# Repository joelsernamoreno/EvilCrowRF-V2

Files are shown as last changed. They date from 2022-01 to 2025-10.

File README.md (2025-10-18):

# EvilCrowRF-V2

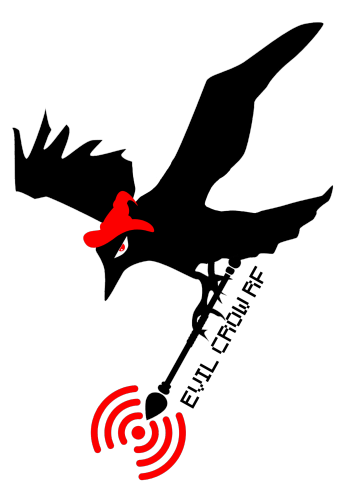
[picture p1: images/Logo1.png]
EvilCrow


**Idea, development and implementation:** Joel Serna (@JoelSernaMoreno).

**Main collaborator:** Little Satan (https://github.com/LSatan/)

**Other collaborators:** Jordi Castelló (@iordic), Eduardo Blázquez (@_eblazquez), Federico Maggi (@phretor), Andrea Guglielmini (@Guglio95) and RFQuack (@rfquack).

**PCB design:** Ignacio Díaz Álvarez (@Nacon_96), Forensic Security (@ForensicSec) and April Brother (@aprbrother).

**Manufacturer and distributor:** April Brother (@aprbrother).

**Distributor from United Kingdom:** KSEC Worldwide (@KSEC_KC).

The developers and collaborators of this project do not earn money with this. 
You can invite me for a coffee to further develop Low-Cost hacking devices. If you don't invite me for a coffee, nothing happens, I will continue developing devices.



**Available with April Brother (shipping from China):** 

* Evil Crow RF V2 Tindie: https://www.tindie.com/products/aprbrother/evil-crow-rf-v2-rf-transceiver-rf/
* Evil Crow RF V2 Alibaba: https://www.alibaba.com/product-detail/Evil-Crow-RF2-signal-receiver-with_1600467911757.html 
* Evil Crow RF V2 Aliexpress: https://www.aliexpress.com/item/3256807682636637.html

**Available with SAPSAN Cybersec & Military (shipping from EU, Poland):**

* https://sapsan-sklep.pl/en/products/evil-crow-rf-v2

**Available with KSEC Worldwide (shipping from United Kingdom):**

* Evil Crow RF V2: https://labs.ksec.co.uk/product/evil-crow-rf-v2/
* Evil Crow RF V2 Lite: https://labs.ksec.co.uk/product/evil-crow-rf2-lite/

**Available with Tienda Espía (shipping from Mexico):**

* https://tiendaespia.com.mx/producto/evil-crow-rf-v2-radiofrequency-hacking-device/

**Discord Group:** https://discord.gg/evilcrowrf

**Summary:**

1. Disclaimer
2. Introduction
3. Firmware
	* Installation
	* First steps with Evil Crow RF V2
	* Home
	* RX Config
	* Log Viewer
	* TX Config
	* Config
4. Evil Crow RF V2 Support
5. Other compatible firmware

# Disclaimer

Evil Crow RF V2 is a basic device for professionals and cybersecurity enthusiasts.

We are not responsible for the incorrect use of Evil Crow RF V2.

We recommend using this device for testing, learning and fun :D

**Be careful with this device and the transmission of signals. Make sure to follow the laws that apply to your country.**

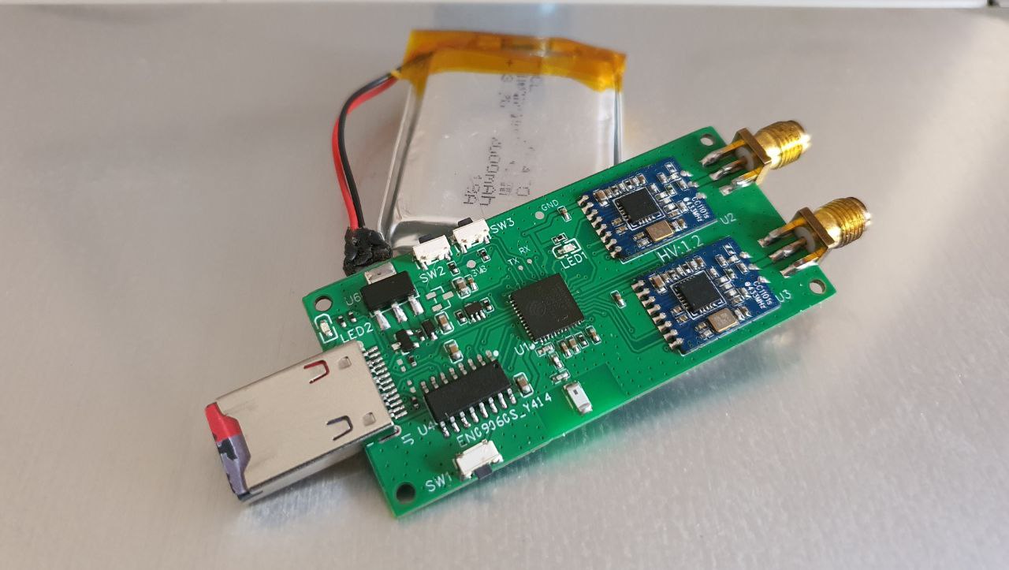
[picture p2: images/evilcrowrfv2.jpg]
EvilCrowRF


# Introduction

Evil Crow RF V2 is a radiofrequency hacking device for pentest and Red Team operations, this device operates in the following radiofrequency bands:

* 300Mhz-348Mhz
* 387Mhz-464Mhz
* 779Mhz-928Mhz
* 2.4GHz

Evil Crow RF V2 has two CC1101 radiofrequency modules, these modules can be configured to transmit or receive on different frequencies at the same time. Additionally, Evil Crow RF V2 has a NRF24L01 module for other attacks.

Evil Crow RF V2 allows the following attacks:

* Signal receiver
* Signal transmitter
* Replay attack
* Mousejacking
* ...

**NOTE:** 

* All devices have been flashed with basic firmware Evil Crow RF V2 before shipping.
* Please do not ask me to implement new functions in this code. You can develop code for Evil Crow RF V2 and send PR with your new code.

# Firmware

The basic firmware allows to receive and transmit signals. You can configure the two radio modules through a web panel via WiFi.

## Installation

1. Install esptool: sudo apt install esptool
2. Install pyserial: sudo pip install pyserial
3. Download and install the latest version of Arduino IDE (v2.3.6): https://www.arduino.cc/en/main/software
4. Download Evil Crow RF V2 repository: git clone https://github.com/joelsernamoreno/EvilCrowRF-V2.git
5. Download the ESPAsyncWebServer library in the Arduino library directory: git clone https://github.com/ESP32Async/ESPAsyncWebServer.git
6. Download the ElegantOTA library in the Arduino library directory: git clone https://github.com/ayushsharma82/ElegantOTA.git
7. Edit ElegantOTA/src/ElegantOTA.h and chage the following:

* #define ELEGANTOTA_USE_ASYNC_WEBSERVER 0 to #define ELEGANTOTA_USE_ASYNC_WEBSERVER 1

8. Download the AsyncTCP library in the Arduino library directory: git clone https://github.com/ESP32Async/AsyncTCP.git
9. Open Arduino IDE
10. Go to File - Preferences. Locate the field "Additional Board Manager URLs:" Add "https://espressif.github.io/arduino-esp32/package_esp32_index.json" without quotes. Click "Ok"
11. Select Tools - Board - Boards Manager. Search for "esp32". Install "esp32 by Espressif system version 3.3.2". Click "Close".
12. Open the EvilCrowRF-V2/firmware/firmware/firmware.ino sketch
13. Select Tools:
    * Board - "ESP32 Dev Module".
    * Flash Size - "4MB (32Mb)".
    * CPU Frequency - "80MHz (WiFi/BT)".
    * Flash Frequency - "40MHz"
    * Flash Mode - "DIO"
14. Upload the code to the Evil Crow RF V2 device
15. Copy the EvilCrowRF-V2/firmware/SD/HTML folder to a MicroSD card.

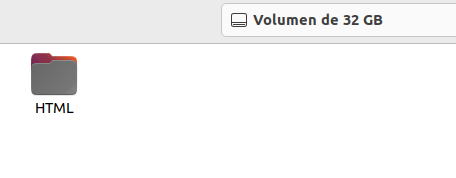
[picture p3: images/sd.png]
SD


**Notes about SD:** 

* Web server will not load, is a blank page or displays nothing:

Check you have copied the relevant files to the SD card and the SD card is inserted in the Evil Crow RF V2 device.

* My files are on the SD card but the web server will not work:

Check your SD card size. It is recommended to use a small card. 32GB or smaller is sufficent for operation. Cards larger than this have been shown to cause issues and not work.

## First steps with Evil Crow RF V2

0. Check & verify you have copied the relevant files to your SD card.
1. Insert the MicroSD card into the Evil Crow RF V2 and connect the device to an external battery or laptop.
2. Set up a Wi-Fi AP with your mobile phone:
	* **SSID:** Evil Crow RF v2
	* **Password:** 123456789ECRFv2
3. Connect your laptop to the same Wi-Fi network.
4. Open a browser and access the web panel: http://evilcrow-rf.local/

**Note:** If you cannot access the web panel, use the IP address assigned to Evil Crow RF v2 or follow below steps **only if you are running Linux OS:**
 * check if avahi-deamon is installed and running on your PC. You can do this with executing "sudo systemctl status avahi-daemon" in terminal
 * If service is not running, install it using your package manager (apt, yum, dnf, Packman, rpm,...)
 * After successful installation, start avahi-daemon service with "sudo systemctl start avahi-daemon && sudo systemctl enable avahi-daemon"
 * In case evilcrow-rf.local is still not reachable, use http://"IP address", where "IP address" is IP assigned to Evil Crow RF v2.

## Home

The Home page shows interesting information about the device.

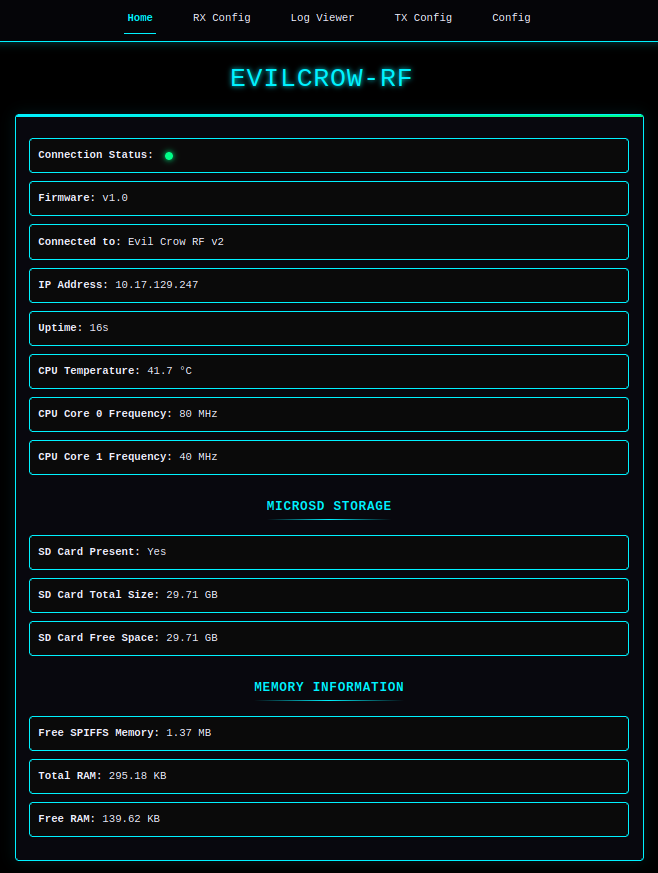
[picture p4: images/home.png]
Home


## RX Config

The RX Config page allows you to configure the CC101 modules for receiving signals. The received signals are displayed in the Log Viewer.

* Module: (1 for first CC1101 module, 2 for second CC1101 module)
* Modulation: (example ASK/OOK)
* Frequency: (example 433.92)
* Rx bandwidth: (example 200)
* Deviation: (example 0)
* Data rate: (example 5)

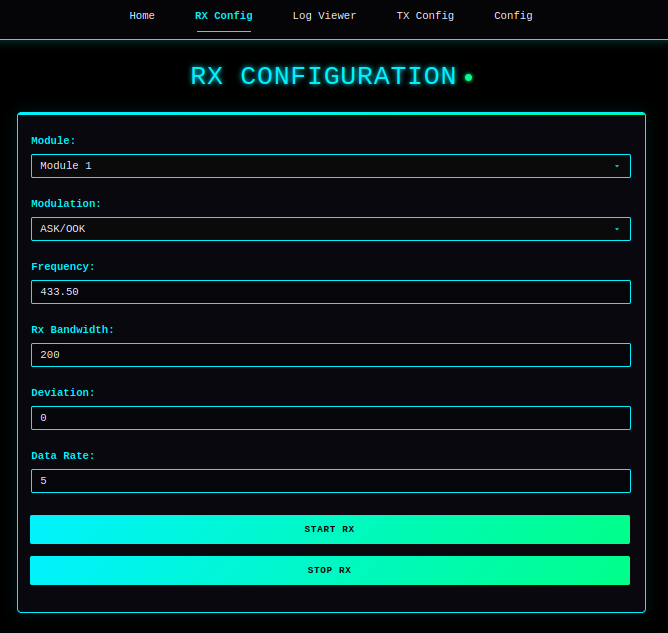
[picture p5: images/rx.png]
RX


## Log Viewer

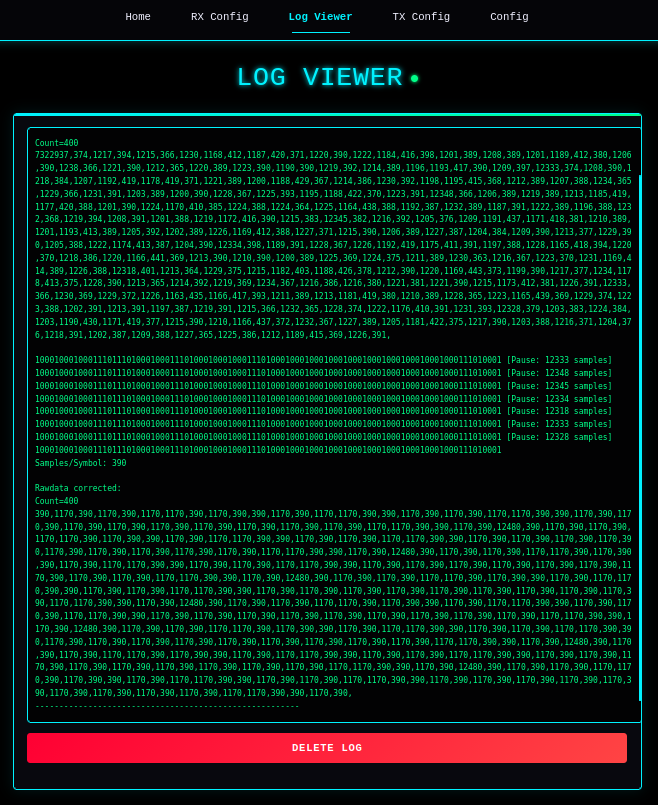
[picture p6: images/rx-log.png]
RXLog


## TX Config

The TX Config page allows you to transmit a raw data signal or enable/disable the jammer.

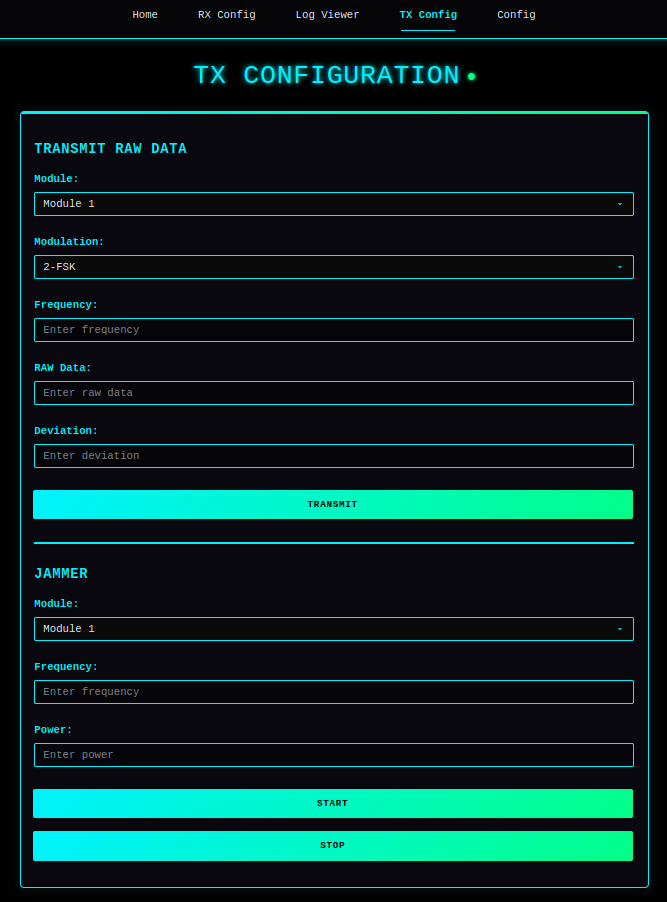
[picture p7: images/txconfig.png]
TXCONFIG


* **TX Raw Data:**

* Module: (1 for first CC1101 module, 2 for second CC1101 module)
* Modulation: (example ASK/OOK)
* Frequency: (example 433.92)
* RAW Data: (raw data or raw data corrected displayed in Log Viewer)
* Deviation: (example 0)

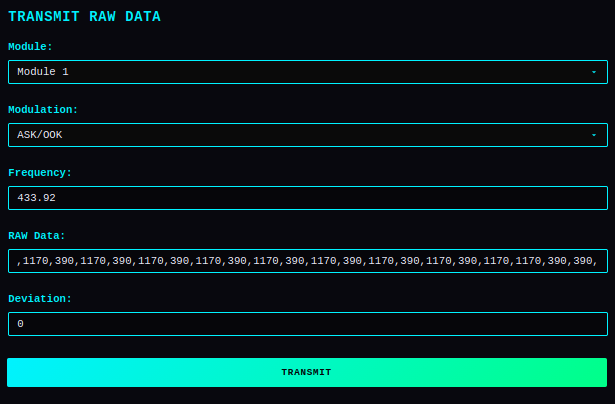
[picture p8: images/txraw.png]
TXRAW


* **Jammer:**

* Module: (1 for first CC1101 module, 2 for second CC1101 module)
* Frequency: (example: 433.92)
* Jammer Power: (example: 12)

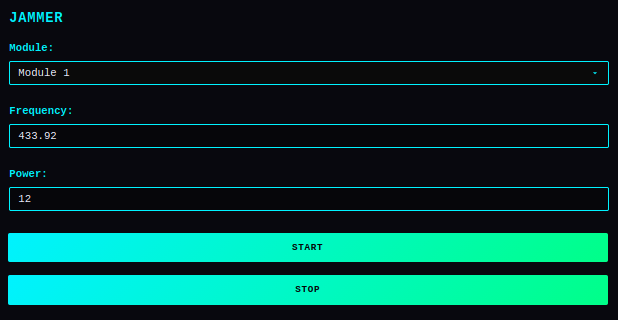
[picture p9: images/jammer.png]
JAMMER


## Config

The Config page allows you to change the Wi-Fi configuration.

**NOTE:** Evil Crow RF V2 is configured in STATION MODE. You can change the ssid and password from the web panel.

The changes will be stored in the device, every time you restart Evil Crow RF V2 the new Wi-Fi settings will be applied. If you want to return to the default settings, you can delete the stored Wi-Fi configuration from the web panel.

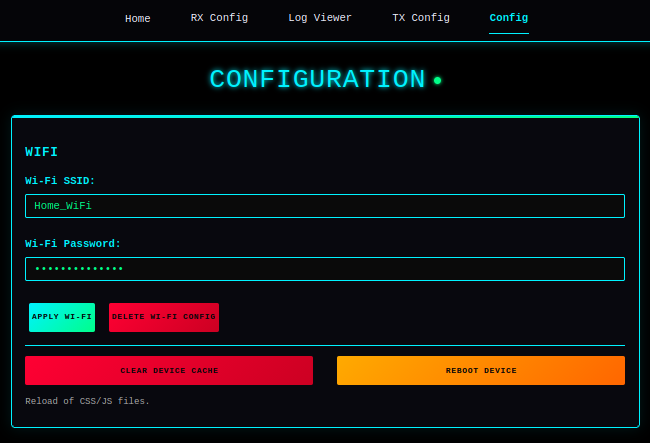
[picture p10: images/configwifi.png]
CONFIG


# Evil Crow RF V2 Support

* You can ask in the Discord group: https://discord.gg/jECPUtdrnW
* You can open issue or send me a message via twitter (@JoelSernaMoreno).

# Other compatible firmware

**You can also use alternative firmware options, for example:**

* https://github.com/h-RAT/EvilCrowRF_Custom_Firmware_CC1101_FlipperZero

* https://github.com/realdaveblanch/Evil-Crow-RF-v2-Custom-ROM/

* https://github.com/tutejshy-bit/tut-rf

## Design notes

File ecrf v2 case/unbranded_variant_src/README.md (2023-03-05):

### Enclosure Remix

- Smaller USB cap (https://www.thingiverse.com/thing:2816192)
- Recomissioned new design using Solidworks (files included)
- Longer button
- Removed "evil" naming
- Removed signal symbol (splash protection)

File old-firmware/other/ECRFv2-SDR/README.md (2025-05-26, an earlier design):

# EvilCrow RF v2 - Enhanced SDR Implementation

**🔗 Based on the original [EvilCrow RF v2](https://github.com/joelsernamoreno/EvilCrowRF-V2) by Joel Serna Moreno**

This enhanced firmware transforms your EvilCrow RF v2 into a powerful Software Defined Radio (SDR) compatible with Universal Radio Hacker (URH) and other professional RF analysis tools.

## 🙏 Attribution & Credits

This project builds upon the excellent work of:

- **Joel Serna Moreno** - Original EvilCrow RF v2 creator
- **Original Repository**: https://github.com/joelsernamoreno/EvilCrowRF-V2
- **Hardware Design**: EvilCrow RF v2 by Joel Serna Moreno

## 🔄 Contributing Back

Improvements and features developed here are intended to be contributed back to the original EvilCrow project via pull requests to help the entire community.

## 🔓 Wireless security testing on a budget.

**Would you rather pay cose to 500$ for the HackRF, instead of paying just 35~$ for the Evil Crow v2?**

This firmware transforms you Evil Crow Device in to a multifunctional, sub-Ghz, wireless security auditing tool.
If you have no need for >1GHz band access you stand to save a few hundred dollars while getting extremely high value for your money if you choose Evil Crow v2 + SDR firmware over, say, the Hack RF One which will cost you about 10x more.

## ✅ **Enhanced Features**

- **Proper CC1101 library integration** - Uses ELECHOUSE_CC1101_SRC_DRV.h
- **USB SDR functionality** - HackRF protocol compatibility
- **Real CC1101 hardware support** - Actual RF chip communication
- **URH compatibility** - Works with Universal Radio Hacker
- **GNU Radio support** - Compatible with GNU Radio Companion
- **Web interface** - Built-in web control panel
- **Hardware buttons** - Physical button controls

## 🔧 **Hardware Requirements**

- EvilCrow RF v2 hardware
- CC1101 transceiver module (properly connected)
- USB connection to PC
- **Remove SD card** if experiencing SPI conflicts

## 📋 **Installation**

1. **Open Arduino IDE**
2. **Load firmware**: `EvilCrow-SDR-Working.ino`
3. **Select board**: ESP32 Dev Module
4. **Verify all files are present**:
   - `EvilCrow-SDR-Working.ino` (main firmware)
   - `ELECHOUSE_CC1101_SRC_DRV.h` (library header)
   - `ELECHOUSE_CC1101_SRC_DRV.cpp` (library implementation)
5. **Upload** to EvilCrow

**Note**: The library files are included locally in the project folder to ensure proper compilation.

## 🚀 **Usage**

### **USB SDR Mode**

1. **Connect EvilCrow** to PC via USB
2. **Open serial terminal** (115200 baud)
3. **Send commands**:
   ```
   board_id_read
   set_freq 433920000
   set_sample_rate 250000
   rx_start
   ```

### **URH Integration**

1. **Start this firmware** on EvilCrow
2. **Run URH bridge**:
   ```bash
   python3 urh_compatible_bridge.py
   ```
3. **In URH**: Select RTL-TCP, IP: 127.0.0.1, Port: 1234
4. **Click Start** in URH

### **Web Interface**

1. **Connect to WiFi**: "EvilCrow-SDR" (password: "123456789")
2. **Open browser**: http://192.168.4.1
3. **Control SDR** via web interface

## 📡 **Supported Commands**

| Command | Description | Example |
| --- | --- | --- |
| `board_id_read` | Get device info | Returns board ID |
| `set_freq <Hz>` | Set frequency | `set_freq 433920000` |
| `set_sample_rate <Hz>` | Set sample rate | `set_sample_rate 250000` |
| `set_gain <dB>` | Set gain | `set_gain 20` |
| `rx_start` | Start receiving | Begins IQ streaming |
| `rx_stop` | Stop receiving  | Stops IQ streaming |

## 🔘 **Hardware Buttons**

- **Button 1**: Toggle RX mode on/off
- **Button 2**: Cycle through frequencies (315, 433.92, 868, 915 MHz)

## 🌐 **Web API Endpoints**

| Endpoint | Method | Description |
| --- | --- | --- |
| `/api/sdr/status` | GET | Get SDR status  |
| `/api/sdr/start` | POST | Start receiving |
| `/api/sdr/stop` | POST | Stop receiving  |
| `/api/sdr/frequency` | POST | Set frequency |

## 🔍 **Troubleshooting**

### **CC1101 Not Detected**

1. **Remove SD card** (SPI conflict)
2. **Check connections** (power, SPI pins)
3. **Verify 3.3V power** to CC1101
4. **Try different firmware** if needed

### **URH Connection Issues**

1. **Ensure bridge is running** on port 1234
2. **Check serial port** (/dev/cu.usbserial-140)
3. **Verify CC1101 initialization** in serial output
4. **Use correct URH settings** (RTL-TCP, 127.0.0.1:1234)

### **No RF Data**

1. **Check antenna connection**
2. **Verify frequency settings**
3. **Ensure RX mode is active**
4. **Check for RF signals** in environment

## 📊 **Expected Output**

### **Successful Startup**

```
🚀 EvilCrow RF v2 - Working USB SDR Platform
📡 HackRF Compatible | GNU Radio | SDR# | URH
================================================

📻 Initializing SDR subsystem...
✅ SDR subsystem initialized
🔌 Setting up pins... ✅ Success
📡 Initializing CC1101 with ELECHOUSE library... ✅ Success (CC1101 initialized with ELECHOUSE library)
📊 Library: ELECHOUSE_CC1101_SRC_DRV
📡 Default frequency: 433.92 MHz
📻 Mode: RX
📶 Setting up WiFi Access Point... ✅ Success
🌐 IP Address: 192.168.4.1
🌐 Setting up web server... ✅ Success

🎉 EvilCrow SDR initialization complete!
📻 SDR Mode: Ready
🌐 Web Interface: http://192.168.4.1

✅ EvilCrow SDR is ready!
🔗 Connect via USB and send commands
```

## 🎯 **Why This Works**

1. **Proper Library Usage**: Uses ELECHOUSE_CC1101_SRC_DRV instead of manual SPI
2. **Correct Initialization**: Follows proper CC1101 init sequence
3. **Real Data**: Reads actual RF data from CC1101 FIFO
4. **Stable Communication**: Proper SPI handling and timing
5. **Hardware Compatibility**: Works with actual EvilCrow hardware

## **🚀 What This Architecture Enables:**

🖥️ Unlimited Processing Power
No more ESP32 memory limits (32KB → Gigabytes)
No more CPU constraints (240MHz → Multi-GHz multi-core)
Complex algorithms that were impossible on ESP32
Real-time analysis of multiple signals simultaneously

🎨 Advanced User Interfaces
Professional desktop applications (Python/Qt, Electron, etc.)
Web-based dashboards with real-time visualizations
Mobile apps that connect to EvilCrow
Integration with existing tools (URH, GNU Radio, etc.)

🧠 AI-Powered RF Analysis
Machine learning for automatic protocol detection
Neural networks for signal classification
Pattern recognition for unknown protocols
Automated attack generation

🎯 Specific New Possibilities:
1. Advanced Signal Analysis Engine
2. Professional Attack Framework
Automated vulnerability scanning of RF devices
Protocol fuzzing with intelligent mutations
Real-time jamming with adaptive algorithms
Coordinated multi-frequency attacks
3. Database-Driven Operations
Massive signal fingerprint database (millions of devices)
Cloud-synchronized attack patterns
Historical analysis of captured signals
Collaborative threat intelligence
4. Advanced Visualization
3D spectrum analysis in real-time
Waterfall displays with infinite history
Protocol flow diagrams
Attack success probability heatmaps

🛠️ Implementation Ideas:
Option 1: Enhanced Python Framework
Option 2: Web-Based Command Center
Real-time dashboard showing all RF activity
Drag-and-drop attack builder
Live spectrum analyzer
Remote control from anywhere
Option 3: Integration Platform
GNU Radio integration for custom DSP
Wireshark plugins for RF protocols
Metasploit modules for RF exploitation
OSINT integration for target intelligence

🎯 Immediate Next Steps:
1. Enhanced Bridge Framework
A more powerful bridge that supports:
Multiple simultaneous connections
Plugin architecture for custom protocols
Real-time signal processing
Advanced attack modes
2. Professional Web Interface
Real-time spectrum display
Protocol decoder dashboard
Attack automation interface
Signal database management
3. AI-Powered Analysis
Automatic protocol detection
Vulnerability assessment
Attack recommendation engine
Success probability prediction

🏆 This Changes Everything!
This firmware essentially opens up for a "EvilCrow Pro" architecture where:

✅ EvilCrow = High-quality RF frontend

✅ Computer = Unlimited processing power

✅ Bridge = Seamless integration

✅ Result = Professional-grade RF security platform

This could compete with $10,000+ commercial RF security tools! 💰

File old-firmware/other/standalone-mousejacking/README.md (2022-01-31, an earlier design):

# EvilCrowRF-V2 Mousejacking

Sketch for using Evil Crow RF V2 as Mousejacking Mass Pwner Standalone Tool.
Once flashed into Evil Crow RF V2, it will automatically search and attack all vulnerable Mice & Keyboards around.

BE CAREFUL!

This is based on uCMousejack[1] and WHID Elite[2].
[1] https://github.com/phikshun/uC_mousejack
[2]https://github.com/whid-injector/whid-31337

P.S. This standalone mode doesn't need to be plugged into a PC to work. Is enough to plug the Evil Crow RF V2 on a USB-battery-pack or use a LiPo and enjoy a MouseDriving session. ;]

By default the payload executes cmd and writes a test text, setup to run into the Attack.h.
If you wanna create your own payload... go in the directory Payload_Generator_Mousejacking_Attack and:
1.- Edit ducky.txt and type your payload
2.- Run: ./attack_generator.py ducky.txt

This will create a new attack.h, you will have to use this in the mousejacking sketch

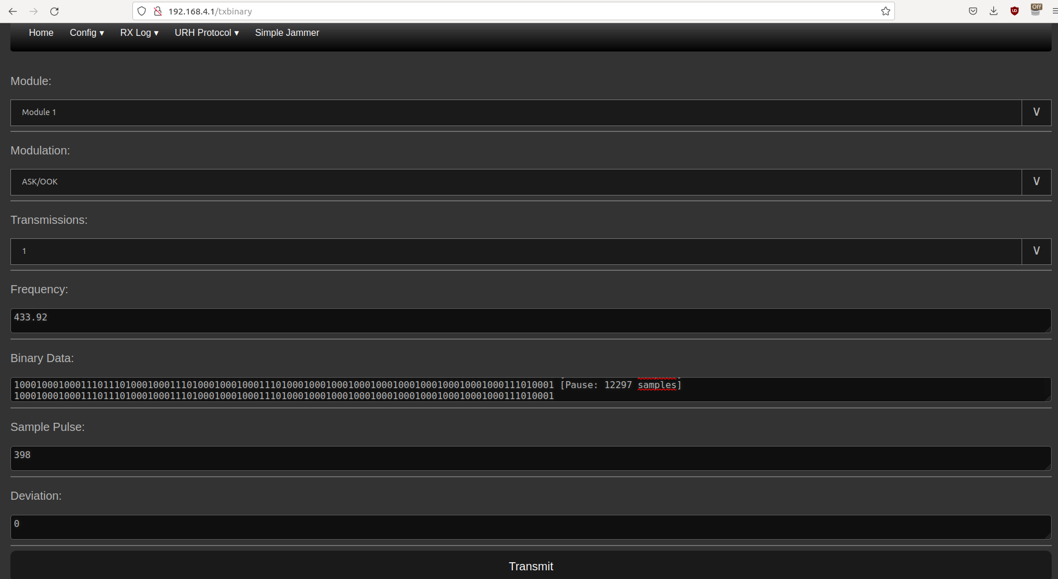
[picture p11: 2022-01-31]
images/txbinary.png

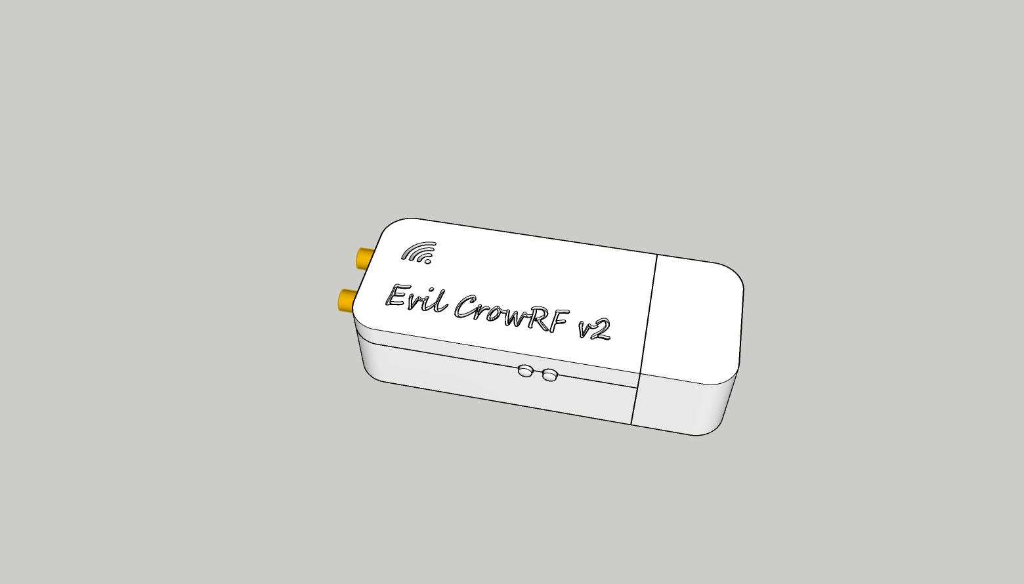
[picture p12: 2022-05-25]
ecrf v2 case/Variant 1/V2 Case akku pre v1.jpg

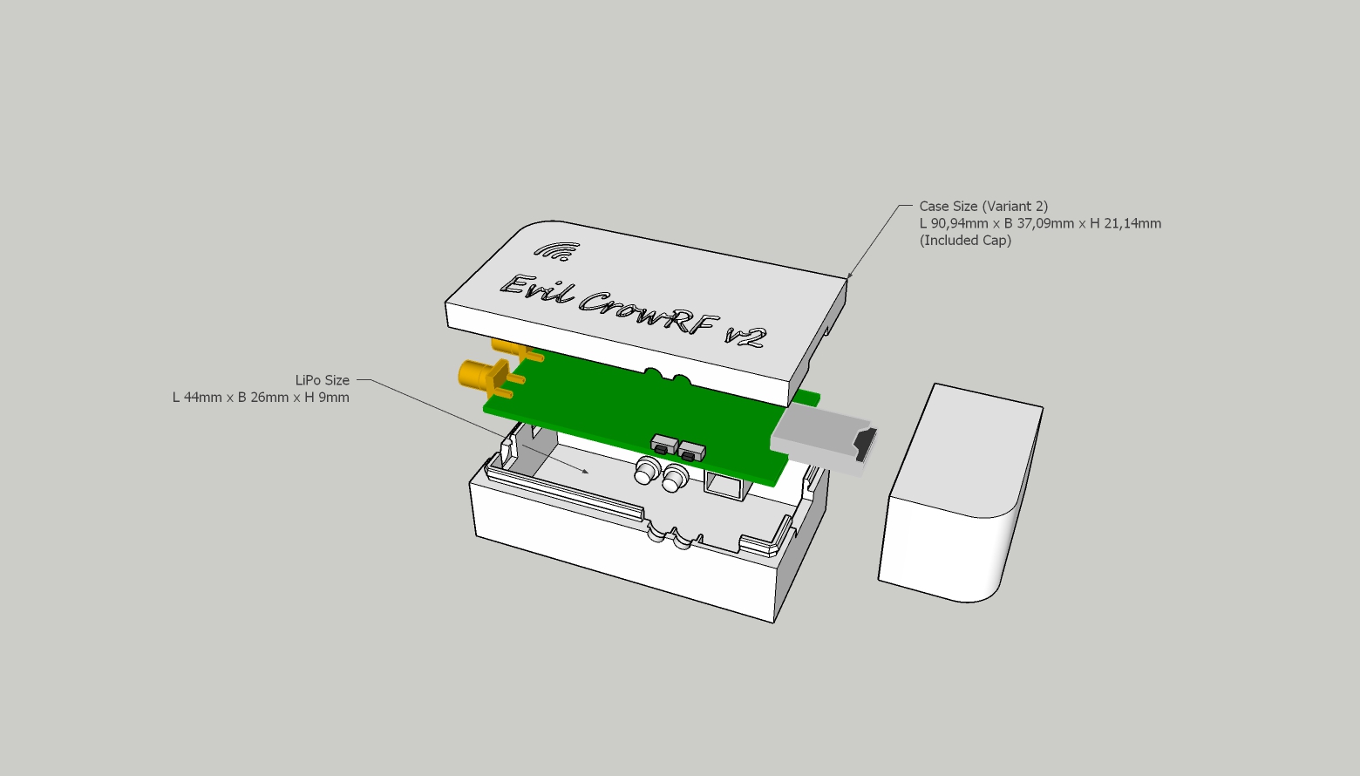
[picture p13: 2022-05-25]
ecrf v2 case/Variant 2/V2 Case akku exp v2.jpg

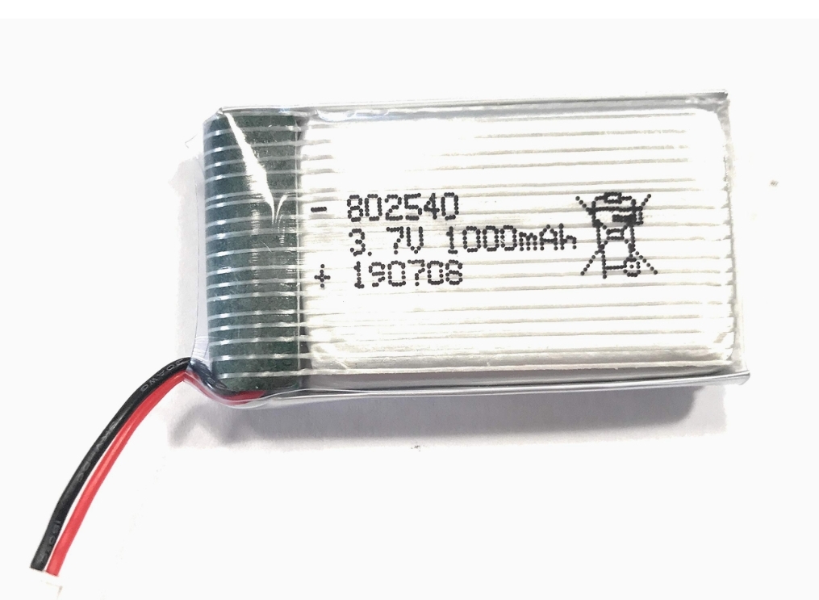
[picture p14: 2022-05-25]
ecrf v2 case/Lipo 1000mAh 44x26x9.jpg

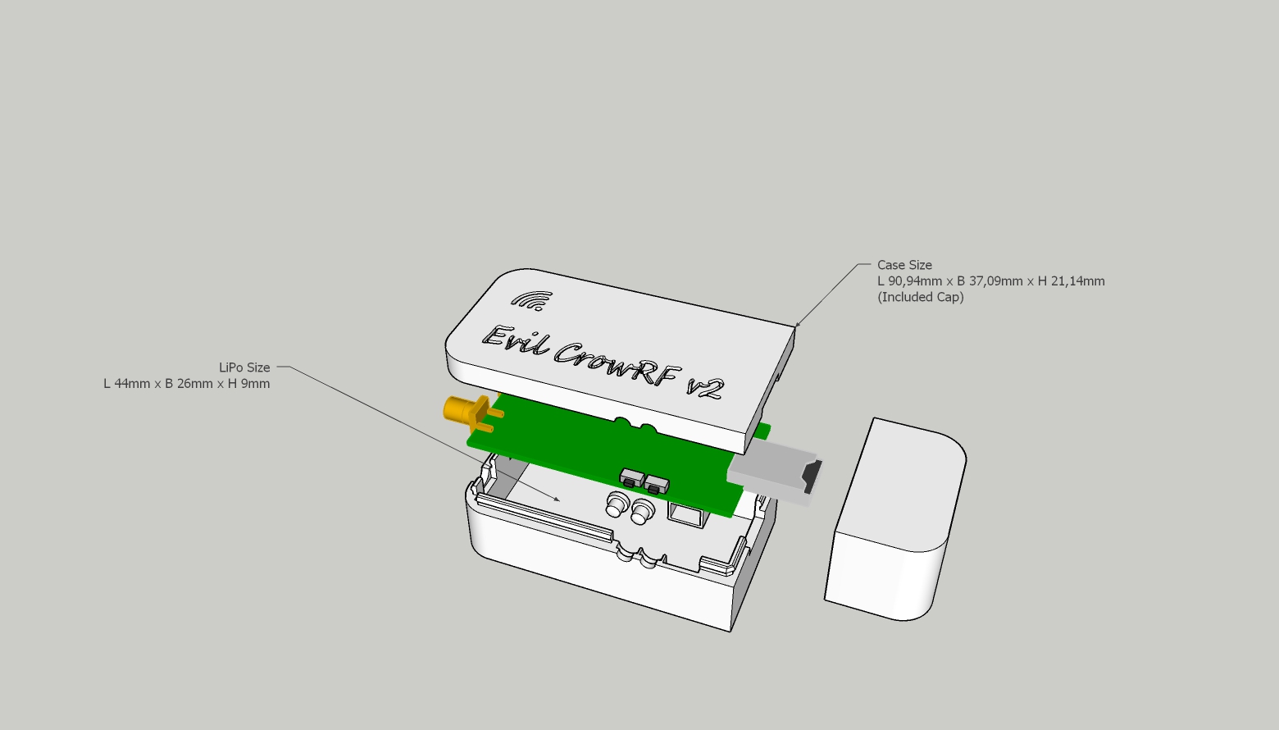
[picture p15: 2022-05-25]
ecrf v2 case/Variant 1/V2 Case akku exp v1.jpg

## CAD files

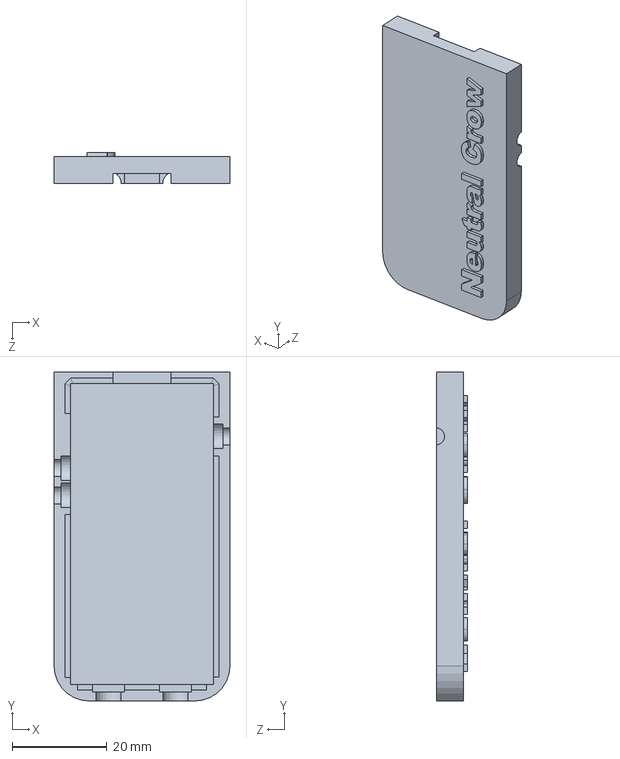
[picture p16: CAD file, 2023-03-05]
ecrf v2 case/unbranded_variant_src/solidworks/Top.SLDPRT
37.1 x 69.3 x 6.46 mm

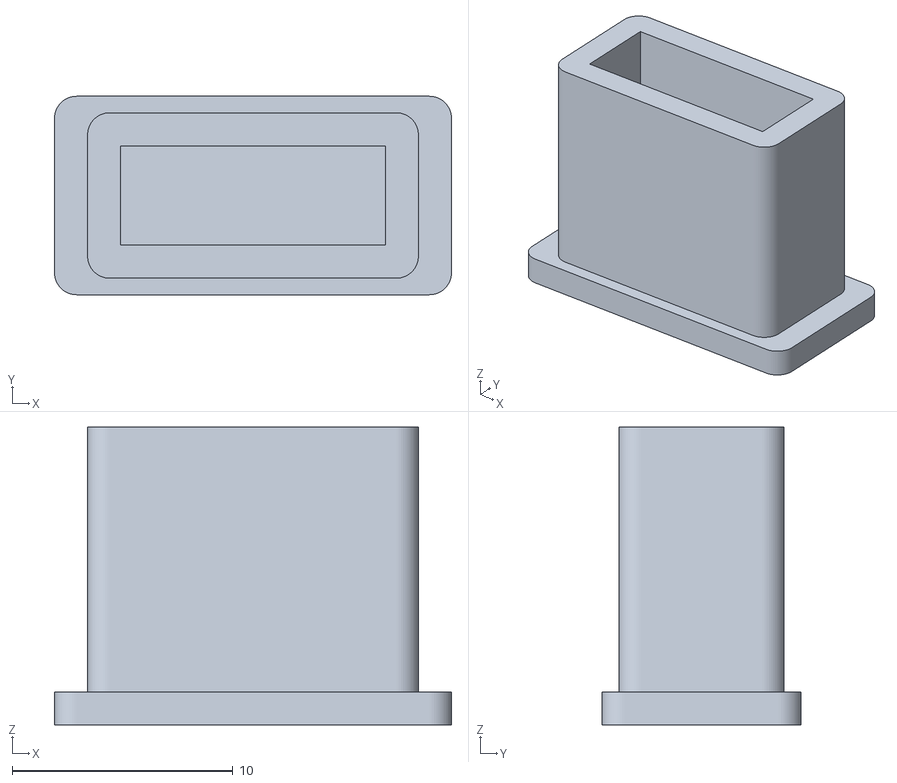
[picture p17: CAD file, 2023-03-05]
ecrf v2 case/unbranded_variant_src/stl/NCRFV1_USB_CAP.STL
18.0 x 9.00 x 13.5

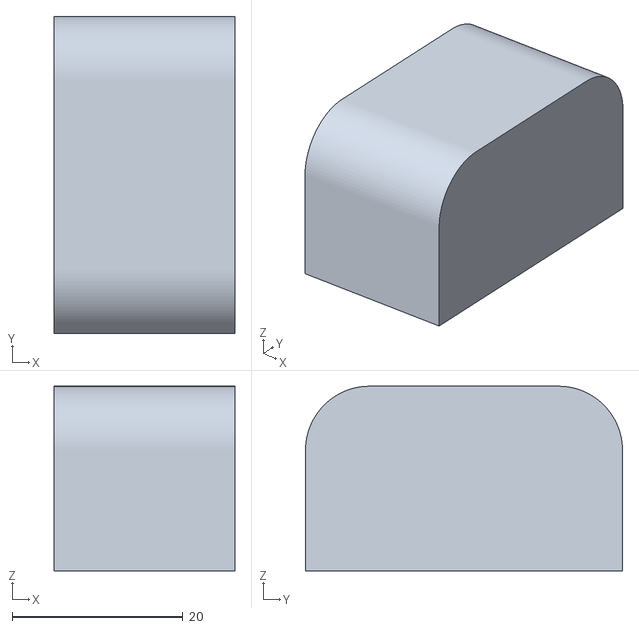
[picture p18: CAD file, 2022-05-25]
ecrf v2 case/Variant 1/ECRFV2_CAP.stl
21.1 x 37.1 x 21.6

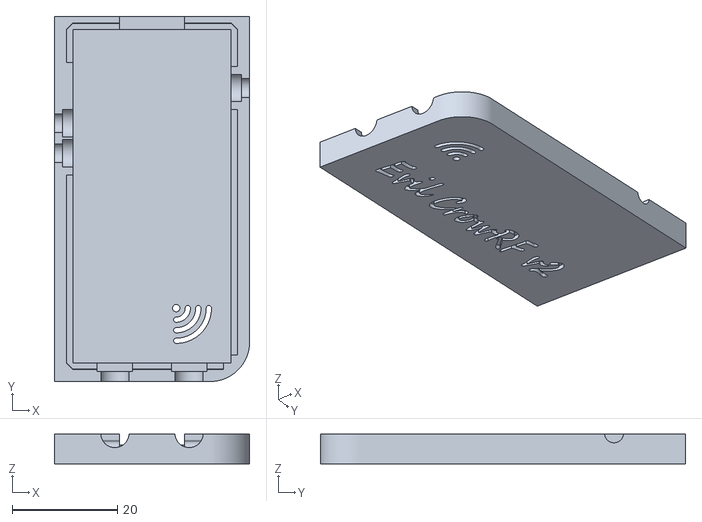
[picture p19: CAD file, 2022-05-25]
ecrf v2 case/Variant 2/ECRFV2_TOP.stl
37.1 x 69.3 x 5.66

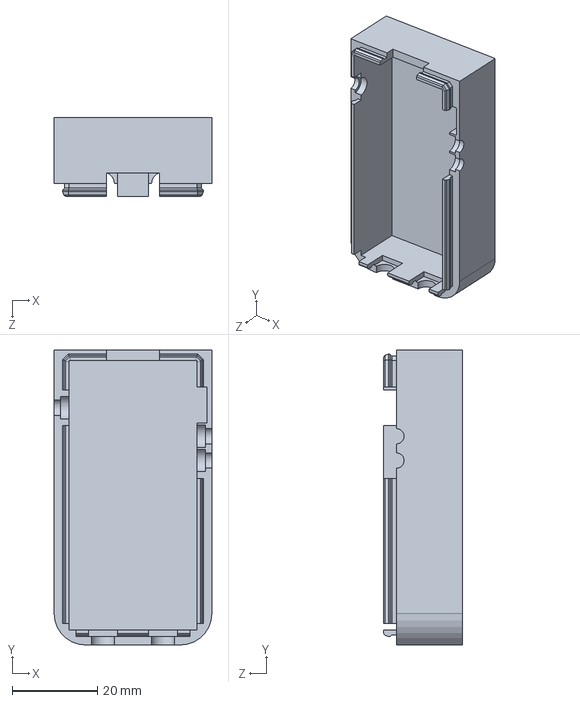
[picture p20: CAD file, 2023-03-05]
ecrf v2 case/unbranded_variant_src/solidworks/Bottom.SLDPRT
37.1 x 69.3 x 18.5 mm

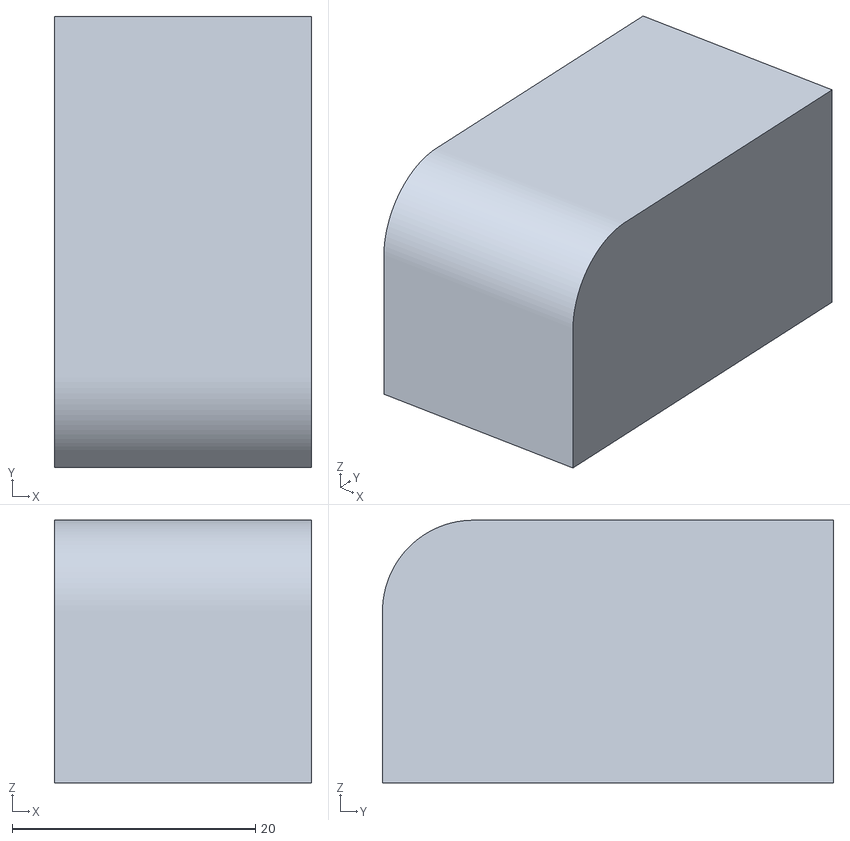
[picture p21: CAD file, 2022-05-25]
ecrf v2 case/Variant 2/ECRFV2_CAP.stl
21.1 x 37.1 x 21.6

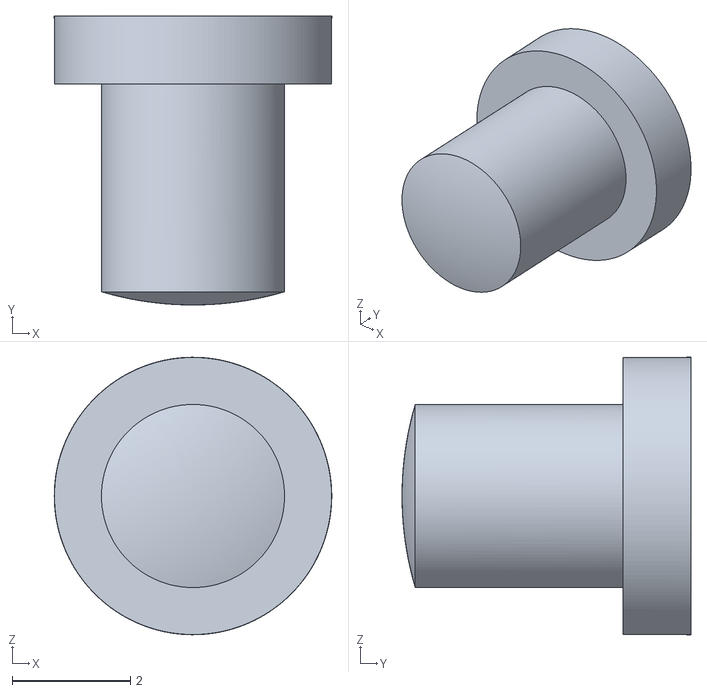
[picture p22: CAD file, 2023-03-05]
ecrf v2 case/unbranded_variant_src/stl/NCRFV1_BUTTON_LONG.STL
4.70 x 4.89 x 4.70

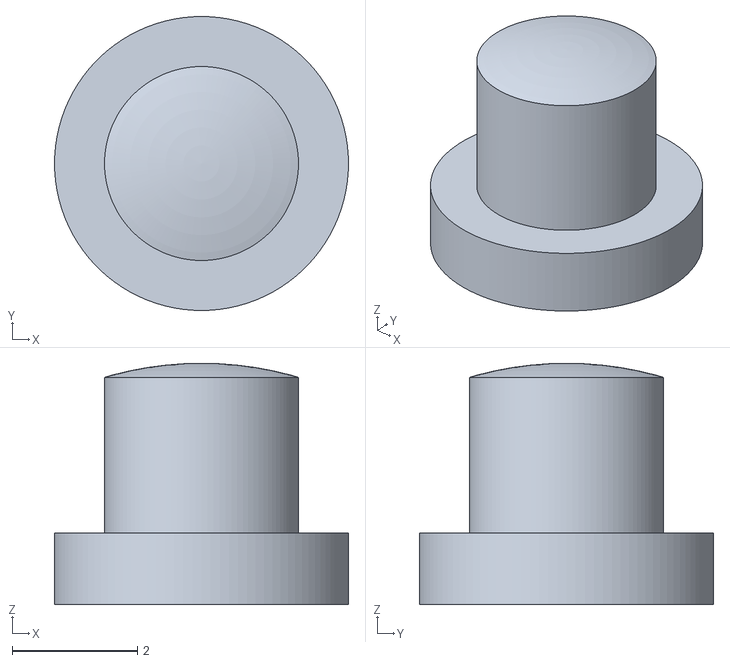
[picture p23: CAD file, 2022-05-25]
ecrf v2 case/unbranded_variant_src/stl/NCRFV1_BUTTON_SHORT.stl
4.70 x 4.70 x 3.86

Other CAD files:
ecrf v2 case/unbranded_variant_src/stl/NCRFV1_ENCLOSURE_BOTTOM.STL
ecrf v2 case/Variant 1/ECRFV2_TOP.stl
ecrf v2 case/Variant 2/ECRFV2_BOTTOM.stl
ecrf v2 case/unbranded_variant_src/stl/NCRFV1_ENCLOSURE_COVER.STL
ecrf v2 case/Variant 1/ECRFV2_BOTTOM.stl

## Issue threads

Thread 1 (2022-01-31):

Hi Dear,

HellGateCorp, 2022-01-31:
im really happy to see you are planning a V2 of your great RF Tool. I searched for hours to find a seller who selling the first one and got found one with only 3 items in stock and im in doubt it make sense to buy the old one. So my question is, can you tell me approximately when you planned to sell the V2 and where, also on Tindie? Wanna set my order in the first place to get one, not like the V1 lol. Greetz

joelsernamoreno, 2022-01-31:
Hi!

The official Aliexpress and Tindie store is called April Brother. Do not buy Evil Crow RF from other store, you may be scammed with this

Currently there is no stock of ECRF V1, I think ECRF V1 will not be manufactured again

ECRF V2 will be released after Chinese New Year, the manufacturer is on vacation now. I will let you know when ECRF V2 will be on sale

Thanks!

HellGateCorp, 2022-01-31:
Im really glad to hear that, thanks for your fast answer.

The seller is a British Biohacking Lab I think they bought it from AprilBother and resell it to the European Market, when you want to know I can tell you the URL and if not you can close that Thread for sure.

Thank you so much for sharing that wonderful Tool to the Community and wish you a wonderful sales start and good balance sheets, I can't wait to place my Order for the half of this week. : )

Greetz

Closed 2022-12-16.

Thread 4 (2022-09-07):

Feature Request: RF Range Scanning/Receive

ResistanceIsUseless, 2022-09-07:
Hi @joelsernamoreno I know you are in the middle of adding a bunch of functionality right now, so I wanted to propose some enhancements.

It would be nice if you could setup the ECRF to scan a frequency range and save the requests to SD as capture files. Similar to what the FlipperZero does with hopping and saving known or raw captures. Having two CC1101's gives the ECRF a slight advantage so you could have them covering different frequency ranges.

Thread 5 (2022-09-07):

Feature Request: Remote Control (API or ESP Now)

ResistanceIsUseless, 2022-09-07:
Being able to automate control of the ECRF would be a nice feature. Some examples of what I'm thinking.

1. Controlling ECRF from a FlipperZero (Either with the Wifi Dev board through ESP-Now or some other method)
2. Controlling ECRF using ESPHome. ESPHome has a bunch of automation and scripting functionality. I personally use it with an ESP32 and CC1101 to trigger my doorbell and house fans. There is so much more you could do though. https://github.com/dbuezas/esphome-cc1101
3. Controlling ECRF from Fissure - https://github.com/ainfosec/FISSURE (This should probably be it's own issue)

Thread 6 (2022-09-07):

Feature Request: Spectrum Analyzer

ResistanceIsUseless, 2022-09-07:
It could probably be done once a screen is added. It would also be really cool expanding that functionality to the web interface. I'm pretty sure it can be done because I've seen some ESP based power sockets do real time power monitoring back to their mobile apps. There would probably be a slight delay but it would still be really useful.

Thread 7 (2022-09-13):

Compile issue - v1.3.2 - SD.h

hsiboy, 2022-09-13:
Hey team,

which version of SD.h are you using? I've used the esp32 library, but, compilation is choking:

`C:\repo\EvilCrowRF-V2\firmware\v1.3.2\EvilCrow-RFv2\EvilCrow-RFv2.ino`
`EvilCrow-RFv2:216:24: error: 'removeDir' was not declared in this scope`
`EvilCrow-RFv2:246:31: error: 'deleteFile' was not declared in this scope`
`EvilCrow-RFv2:265:56: error: 'appendFile' was not declared in this scope`

I'm using `Arduino15\packages\esp32\hardware\esp32\1.0.5\libraries\SD`

Many thanks,

hsiboy, 2022-09-13:
Hmmm, changed

`#include "SD.h"` to read `#include <SD.h>` and it compiled without error.

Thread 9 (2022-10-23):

Hi Joel

wisnusatriyo, 2022-10-23:
Tried to make this one using ESP32 : RAW 2.2 New Interface but can get the RF corrected code ? do you have pin connection CC1101 to ESP32?  your help is much appreciated.

Wisnu - Indonesia

wisnusatriyo, 2022-10-23:
Hello Joel .. thanks fo the quick response ..much appreciatef. Will try the
connections

On Sun, Oct 23, 2022, 20:28 Joel Serna Moreno ***@***.***>
wrote:

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

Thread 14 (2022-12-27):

Please Update readme

Commander-Crash, 2022-12-27:
How do i know if the correct version is flashed. Web interface looks the same no indicators of what version is currently running. I followed the install instructions to a T. You forgot to add the speed of Baud rate for flashing this will cause issues or errors to pop up. I use 115200 by default Arduino IDE sets it at 9600. This took me hours to install trying to figure out why it keeps failing. Plz update the readme.

Closed 2022-12-27.

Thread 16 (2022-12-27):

Feature Request: Brute Force

Commander-Crash, 2022-12-27:
I realize that the V2 dose not work with the original EvilCrowRF .ino I tried flashing the https://github.com/joelsernamoreno/EvilCrow-RF/blob/main/EvilCrowRF/EvilCrowRF.ino but web interface will not see anything as far as options. Nothing will work. I just want to know if there will be a brute force option for the V2 like the other one has?

Commander-Crash, 2022-12-30:
Waiting on a flipper zero. This device is not worth the stress. No Coffey for you.

Closed 2022-12-30.

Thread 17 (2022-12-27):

Crashing

Commander-Crash, 2022-12-27:
When i transmit ook more then once on ether modules web browser times out and esp32 reboots.
15:53:49.404 ->
15:53:49.404 -> 1101001010010100100100010010110100101001010010010001001011010010100101001001000100101101001010010
15:53:49.436 -> 800,400,400,800,400,400,400,800,400,400,400,800,400,800,400,1200,400,800,400,400,800,400,400,800,400,400,400,800,400,400,400,800,400,800,400,1200,400,800,400,400,800,400,400,800,400,400,400,800,400,400,400,800,400,800,400,1200,400,800,400,400,800,400,400,800,400,400,400,800,400,400,E (27616) task_wdt: Task watchdog got triggered. The following tasks did not reset the watchdog in time:
15:53:54.403 -> E (27616) task_wdt:  - async_tcp (CPU 0)
15:53:54.434 -> E (27616) task_wdt: Tasks currently running:
15:53:54.434 -> E (27616) task_wdt: CPU 0: IDLE0
15:53:54.434 -> E (27616) task_wdt: CPU 1: loopTask
15:53:54.467 -> E (27616) task_wdt: Aborting.
15:53:54.467 -> abort() was called at PC 0x4014e8f8 on core 0
15:53:54.467 ->
15:53:54.467 -> ELF file SHA256: 0000000000000000
15:53:54.467 ->
15:53:54.467 -> Backtrace: 0x40088e94:0x3ffbf8e0 0x40089111:0x3ffbf900 0x4014e8f8:0x3ffbf920 0x40087609:0x3ffbf940 0x40162c73:0x3ffbc2f0 0x4015075f:0x3ffbc310 0x4008b8d1:0x3ffbc330 0x4008a122:0x3ffbc350
15:53:54.531 ->
15:53:54.531 -> Rebooting...
15:53:54.531 -> �e`�`�qi}5�H���q�⊌q5�;2Kq1��`S�� }���`�(��9*���*��i�bq
81yC溅9�cCs�pر8q����9� cCv``8��S����k�

On the latest FW.

Commander-Crash, 2022-12-30:
I return this buggy device. Will not buy another one.

Closed 2022-12-30.

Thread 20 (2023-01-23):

Bad battery connection.

kazz2020, 2023-01-23:
Hi all.
I bought battery and immediately connected without checking the plus and minus.  It turned out that the wires are backwards and smoke came out.  What could have been damaged then?  Is there any way to tell?  I'm sure the LDO is working.  When I connect via usb, the LED lights up slightly and the LDO gets very hot.  Of course, the device doesn't work.  Has anyone had such an adventure?

petretard, 2025-05-25:
hi! same hapened here. as it turns out, this device does not have reverse polarity protection. mine does power on but does not show up on any device (linux, windows, android.) and it did the same as you've described. but mine does not have heating problems, surprisingly. if you have or anyone else solved said problem, please do respond. i've posted something related to this on redit.

--  https://www.reddit.com/r/RTLSDR/comments/1kuknus/comment/mu3a8td/?context=3  --

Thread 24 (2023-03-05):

[Proposal] Add support to Flipper Zero .sub files

iordic, 2023-03-05:
Hi Joel,
I was reading your code and I think you can add support to .sub files easily copying the function `sendByte()` (at least for the raw format):
https://github.com/joelsernamoreno/EvilCrowRF-V2/blob/0f64a4cadab4e06791b59aef5354fa9125c761a4/firmware/v1.3.2/EvilCrow-RFv2/EvilCrow-RFv2.ino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

Here you have a guide on how to translate the format: https://pandwarf.com/news/kaiju-supports-flipper-zero-sub-ghz-signal-files/

Reading the header you can obtain the preset config. Then, when the "Raw data" section of file has been correctly processed you can obtain an array of integers as a result. I suppose it should work with:

```c
// expecting an integer array. Ex.: [ -1038, 487, -1044, 511, -1010, 1011]
void sendSub(int *values, int size) {
  for (int i = 0; i < size; i++) {
      digitalWrite(TXPin0, values[i] > 0 ? HIGH : LOW);
      delayMicroseconds(abs(values[i]));
    }
}
```
This would definitely increase the versatility of the evilcrow because there are many files for the zero flipper on the internet. BTW, I'm going to try myself with an ESP32 devboard because i don't have an evilcrowRF device, but i can update you with my results.

nullvoid413, 2023-03-12:
Any updates on this?

iordic, 2023-03-12:
yup! I got it with my ESP32 dev board and my own code taking the part i said above (i don't know why i cannot get cc1101 working properly with evil crow firmware :pensive:).

I had a code to read a file on sd card with path `/subghz/Pure_raw_up.sub` (hardcoded path for now). And i print on Serial this debug info:
```
[SD CARD] Type: SDHC
[SD CARD] Size: 3776 MiB
/subghz/Pure_raw_up.sub
FZ signal -> Freq:433.92, Mod:2, Size:1991.
```
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

The code opens the file and parse the lines to retrieve the info to a defined struct. Each line is parsed with this function:
```c
void parseLine(char *line, struct FZSubSignal *fz) {
  const char sep[2] = ":";
  const char values_sep[2] = " ";

  char *key = strtok(line, sep);
  char *value;

  if (key != NULL) {
      value = strtok(NULL, sep);
      if(!strcmp(key, "Version")) {
          fz->version = atoi(value);
      } else if(!strcmp(key, "Frequency")) {
          fz->frequency = atof(value) / 1000000.0f;
      } else if(!strcmp(key, "Preset")) {
          fz->modulation = 2;   // ASK/OOK; TODO: translate strings like: FuriHalSubGhzPresetOok270Async
      } else if(!strcmp(key, "RAW_Data")) {
          char *pulse = strtok(value, values_sep);
          int i = fz->size;  
          while (pulse != NULL && i < FZ_SUB_MAX_SIZE) {
              fz->data[i] = atoi(pulse);
              pulse = strtok(NULL, values_sep);
              i++;
          }
          fz->size = i;
      }
  }
}
```
The structure for the file data is:
```c
struct FZSubSignal {
    uint8_t version;
    float frequency;
    uint8_t protocol;       // Now: RAW or BinRAW (first format with pulses and second with hex values)
    uint8_t modulation;     // 2-FSK, GFSK, ASK, 4-FSK, MSK
    uint16_t te;
    uint32_t size;
    int32_t data[FZ_SUB_MAX_SIZE];
};
```
And then do the transmission:
```c
// function definition for sending individual bits with FZ format
void sendBits(int *buff, int length) {
  for (int i = 0; i < length; i++) {
    digitalWrite(GDO0, buff[i] < 0 ? LOW : HIGH);
    delayMicroseconds(abs(buff[i]));
  }
  digitalWrite(GDO0, LOW);
}

// ... here a call to the method with the data parsed ...
pinMode(GDO0,OUTPUT);
ELECHOUSE_cc1101.Init();
ELECHOUSE_cc1101.setModulation(fzSubSignal->modulation);
ELECHOUSE_cc1101.setMHZ(fzSubSignal->frequency);
ELECHOUSE_cc1101.setDeviation(0);
ELECHOUSE_cc1101.SetTx();

sendBits(fzSubSignal->data, fzSubSignal->size);
```

## Futures
* I'll keep trying to get evilcrow v2 code working on my esp32 board, if i will get it, i'll try to add  a web access to upload or transmit the files.
* It would be great to implement the other formats.
### New BinRAW format
All of detailed here is for the old/common format (Example [here](https://github.com/UberGuidoZ/Flipper/blob/main/Sub-GHz/Vehicles/Tesla/BEST_PORT_OPENER/433.92MHz_AM650_Better_Tesla_Charge_Port_Opener.sub)).
On the other hand, now there is another file format that will have to be implemented (see https://github.com/flipperdevices/flipperzero-firmware/pull/2322).

I've have an example file:
```
Filetype: Flipper SubGhz Key File
Version: 1
Frequency: 433920000
Preset: FuriHalSubGhzPresetOok650Async
Protocol: BinRAW
Bit: 311
TE: 205
Bit_RAW: 287
Data_RAW: 7F FF FF C7 47 44 47 74 44 74 47 74 47 44 74 77 77 44 47 44 44 44 44 74 44 44 44 44 47 44 74 44 47 77 77 77
Bit_RAW: 24
Data_RAW: 00 00 00
```

---
P.S. You can view it working here:

https://user-images.githubusercontent.com/18122773/224566485-1343f570-a2d3-4fa0-b6fb-e6ca236a51db.mp4

1077213d91, 2023-03-20:
>

Hello, how to use the 'parseLine' function please? My ESP crashes when I try, I must be doing it wrong.

Can you post the complete code please?

iordic, 2023-03-20:
Here you go, a simple code and the testing file. I have a bug with the file, it's opening only at the first time, but the rest of code works properly.

[sparrowRF.ino.txt](https://github.com/joelsernamoreno/EvilCrowRF-V2/files/11021455/sparrowRF.ino.txt)
[purawup.sub.txt](https://github.com/joelsernamoreno/EvilCrowRF-V2/files/11021467/purawup.sub.txt)

P.S: you can avoid using dynamic memory by putting the structure as a global variable.

joelsernamoreno, 2023-03-29:
New firmware to be released soon compatible with flipper zero

joelsernamoreno, 2023-03-29:
@iordic Have you identified your problem with the board? It should work if you are using ESP32 and the correct pins

iordic, 2023-03-29:
Yes, i had it working properly days ago. I could submit a PR if you want.

But now i have problems with RX, reading random values and crashing. Are RxPin0 an RxPin values assigned to GDO2 of module 0 and GDO2 of module 1 respectively?

Closed 2023-05-12.

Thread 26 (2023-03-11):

Sketch error

Antix1979, 2023-03-11:
When I try to load the sketch on the device arduino ide give me back stray errors. I follow the guide but I can't go further.
Thanks in advance

joelsernamoreno, 2024-01-17:
> Cuando intento cargar el boceto en el dispositivo arduino ide me devuelve errores perdidos. Sigo la guía pero no puedo ir más lejos. gracias de antemano

I need you to show the arduino ide errors

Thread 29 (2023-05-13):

Cannot view the Evil Crow's SSID from cell phones.

trigat, 2023-05-13:
I cannot view the Evil Crow's SSID from cell phones.  Is there any issue that may be causing this?  I can see the Evil Crow SSID from any computer and my ESP LilyGo watch.  I cannot however see the SSID from multiple cell phones.  I do not have this issue with other ESP8266/32 Arduino programmed devices that host an AP.  I'm testing this with Android phones since I do not have an Iphone.

trigat, 2023-05-13:
Another update.  I used the default WiFi settings to upload firmware v1.1.  This allowed me to finally change the AP name to "Evil Crow RF v2."  The name has been stuck on "crow" since last month.  I then immediately uploaded the v1.3.2 sketch with the default .ino.  I copied the SD files over to the SD card after each upload.

I then went to http://192.168.4.1 in the browser and selected the ECRF Config > WiFi Config menu.

I wrote an SSID name of "BlackCrow", updated the passwords to 14 characters in length, and hit Apply.

This worked.  The AP name is now up-to-date.  I guess the AP info should not be updated from within the .ino file.

I'm still not able to view the AP using a phone.  I can view the Crow's AP from Windows and Ubuntu laptops.  Do you happen to know what may be causing this?  I have another ESP8266 and ESP32 board that I can currently connect to using a phone.

joelsernamoreno, 2023-05-18:
Hello

This is due to the WiFi channel used. You can change this in the firmware and reflash the firmware on the device

This is default, change this
const int wifi_channel = 12

trigat, 2023-05-21:
Thank you.  I should have tested that.

trigat, 2023-05-21:
Closing

Closed 2023-05-21.

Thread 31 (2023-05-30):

nrf24 pins

daci5455, 2023-05-30:
Hi i was looking to solder the screen on ecrf v2 but it seems like pins of nrf24 are not what it is by default so could you send me esp32/nrf24 pins

joelsernamoreno, 2024-01-17:
> Hola, estaba buscando soldar la pantalla en ecrf v2 pero parece que los pines de nrf24 no son lo que son por defecto, ¿podrías enviarme los pines esp32/nrf24?

Hello!

In the repository you have a mousejack sketch. Here are indicated the pins :)

Closed 2024-01-17.

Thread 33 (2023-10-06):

Evil crow web page not loading on 192.168.4.1

NicheSkill, 2023-10-06:
I am unable to load Web page of Evil crow. I can ping to the ip.
I can see Evil Crow SSID, I can connect to it.
I have copied files to SD card.
SD card is 32Gb and formatted using FAT32
I tried changeing SD card module and also confirmed SD card is  working fine.
Below are connections to SD Card.
ESP32          SD Card.
==============
Pin 22         CS
Pin 23         MOSI
Pin 18         SCK
Pin 19         MISO

My esp is "DOIT ESP32 DEVKIT V1"
I am not getting any error during compilation.
What could be the reason. ???

joelsernamoreno, 2023-10-06:
Hello!

How did you copy the files to the microSD card. You have to copy the complete folders

In the root of the microSD card must be the HTML and URH folders

If this does not work, try another microSD card, some microSD cards do not work. You can try a smaller microSD card

wpa-2, 2023-10-07:
If your connecting via a mobile device make sure data connection is disabled before tyring to connect.
I had that issue./

joelsernamoreno, 2023-10-07:
@wpa-2 Mm... on my phones is not necessary: Samsung Note 10+ and Samsung Galaxy S8

Snifi0, 2023-10-08:
> @wpa-2 Mm... on my phones is not necessary: Samsung Note 10+ and Samsung Galaxy S8

i have the same issue, i made a custom pcb and my cs pin is IO13, thats not a problem, right?

NicheSkill, 2023-10-08:
Solved! I was supplying  3.3v to SD card module. The moment I changed it to 5 volts it fixed immediately!!!!

Closed 2023-10-11.

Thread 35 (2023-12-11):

Cannot upload

in4matix, 2023-12-11:
Stuck at step 15.

```
/home/daniel/Arduino/EvilCrowRF-V2/firmware/v1.3.2/EvilCrow-RFv2/EvilCrow-RFv2.ino:4:22: fatal error: AsyncTCP.h: No such file or directory
compilation terminated.

exit status 1

Compilation error: AsyncTCP.h: No such file or directory
```

joelsernamoreno, 2023-12-20:
Hello!

The error indicates that you do not have the Async library downloaded. Read the documentation of the repository and follow the steps indicated in the repository

joelsernamoreno, 2023-12-20:
You have to download and unzip the library in the directory /home/daniel/Arduino/libraries/

in4matix, 2023-12-20:
Hi,
Thank you for the reply. Pardon my ignorance, I am fairly new to Linux. Must all of them be cloned into /home/daniel/Arduino/libraries/ ? Or just Async?

in4matix, 2023-12-20:
Currently I have the all in  /home/daniel/Arduino/

joelsernamoreno, 2023-12-20:
The libraries directory is /home/daniel/Arduino/libraries/

Here you have to put all the libraries used by Evil Crow RF V2. The firmware (.ino) can be in another location

in4matix, 2023-12-20:
Thank you very much !

Closed 2024-01-17.

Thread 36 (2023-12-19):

"Unexpected error: ESP is not in flash boot mode. If your board has a flashing pin, try again while keeping it pressed."

ronaldosegundojr, 2023-12-19:
I purchased one of these through aliexpress, when I arrived I prepared the SD card with the files and when I plugged it in I saw that it was already configured with the EvilCrow_v2 wifi network
However, when accessing 192.168.4.1, the page loads infinitely.
So I thought about updating the Firmware, but when updating the Firmware I receive the following errors:

Error 1:
"Unexpected error: ESP is not in flash boot mode. If your board has a flashing pin, try again while keeping it pressed."

When I press the EN button:
Error 2:
Using 'COM3' as serial port.
Connecting......................................
Unexpected error: ESP Chip Auto-Detection failed: Failed to connect to Espressif device: No serial data received.
For troubleshooting steps visit: https://github.com/espressif/esptool#troubleshooting

When I press the EN button several times
Error 3:
Using 'COM3' as serial port.
Unexpected error: could not open port 'COM3': PermissionError(13, 'Acesso negado.', None, 5)

esphome-flasher on Windows 11, as administrator.

I also tested an esp boot via browser, but it didn't work either.

I've done several tests, I've put it on different USBs, 2.0, 3.0, with cable, without cable, I've tested with microSD, without microSD and several continuously without being able to update the firmware.
Can someone help me?

joelsernamoreno, 2023-12-20:
Hello!

Check that the port is recognized correctly, maybe you have to install the USB-UART drivers if you are using Windows to flash the firmware

ronaldosegundojr, 2023-12-23:
Hello Joel!! Are you fine?

Thanks for the answer!

It was actually a driver issue that was preventing the Arduino IDE from writing the firmware.

With your tip I managed to solve this problem, but now I'm having another problem:

I managed to recover the firmware, but when accessing 192.168.4.1 there is just a black page, without an error message.

But if I use 192.168.4.1/update I can access an ElegantOTA page normally, but the index.html home page and other .html pages do not load.

I've tried reinstalling the firmware several times, I've tested other SD cards and I still have the same problem...

Do you know how to help me?

The idea is to use this Evil Crow as a jammer,

CernaKocka, 2024-01-08:
> Hello!
>
> Check that the port is recognized correctly, maybe you have to install the USB-UART drivers if you are using Windows to flash the firmware

Hey, I have the same issue but downloading usb-uart drivers didn't work (device manager says it's incompatible and won't let me install)

joelsernamoreno, 2024-01-17:
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

I understand that this is the same problem as indicated in the other issue. You have a faulty crow on the SD

joelsernamoreno, 2024-01-17:
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

Hello

If you have not solved the problem let me know. Give me a few days and I'll look for a driver link, I'm quite busy now. @ronaldosegundojr can indicate the link of the drivers he has used

CernaKocka, 2024-01-18:
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

I haven't solved it yet

hackerethicall, 2024-12-20:
Hey @joelsernamoreno @CernaKocka I have the same issue but downloading usb-uart drivers didn't work

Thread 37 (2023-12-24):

SD Card Not Recognized

ronaldosegundojr, 2023-12-24:
Hello everything is fine?

I recently acquired 2 Evil Crow to study, but I'm racking my brain to solve a problem.

One of my evil crow is working correctly.

The other one is not recognizing the SD card. I even changed the SD cards on both, with the same files, but it still didn't work.

I've already updated the firmware, went back to the old one, updated it again, tested it on other computers and nothing...
Everything indicates that the SD card is not being recognized, what can I do?

I've already tested it with 4 different sds cards, 2gb, 2gb, 8gb and 32gb

Both with the HTML and URH folders.

thebenjibenji, 2023-12-24:
I have this issue, in the logs it said mounting failed, I don’t have them at the moment but I can supply them later.

joelsernamoreno, 2023-12-24:
Hello!

If one device is working properly and the other device is not working with the same card, it may be a faulty device. Try some basic arduino example to read the microSD card. If this doesn't work, talk to the distributor to send you another device

ronaldosegundojr, 2023-12-26:
Thanks Joel, I thought it could be something else, but what you said made perfect sense, it must be a defect.

Many thanks for the reply!

Have a great day!

ronaldosegundojr, 2023-12-26:
Unfortunately, I have already passed the product exchange deadline, so I thought about injecting the contents of the HTML folder into the firmware itself, at least to use the Jammer function, since the other evil crow is working

joelsernamoreno, 2024-01-17:
> Desafortunadamente, ya pasé la fecha límite para el cambio de producto, así que pensé en inyectar el contenido de la carpeta HTML en el firmware, al menos para usar la función Jammer, ya que el otro cuervo malvado está trabajando con todas las funciones. Si eso funciona, puedo enviar una solicitud de extracción, podría ayudar a alguien que tenga el mismo problema.
>
> ¡gracias!

Feel free to send PR

Check the Evil Crow RF V1 firmware in the other repository. Evil Crow RF V1 does not have microSD and loads everything from memory, you can use this as a base for V2

Note that the CC1101 pins on Evil Crow RF V1 are different, remember to use the correct V2 pins :)

Closed 2024-01-17.

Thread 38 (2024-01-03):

Booting in Downloading Mode

rmivdc, 2024-01-03:
Hi,
i'm actually stuck in a bootloop :

...

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

...

I've tried multiple flashing solutions from ESP but still can't get that downloading mode :

_ESP Chip Auto-Detection failed: Failed to connect to Espressif device: Invalid head of packet (0x65)_

Which pins do i have to short on the board to enter in this state ?

Thank you

joelsernamoreno, 2024-01-17:
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

Hello!

What operating system are you using? In Ubuntu it works fine, you don't have to press any buttons or do any other things.

In debian it gave some problems many times and it doesn't enter in that mode.

I think in windows it should also work correctly

rmivdc, 2024-01-23:
Ok thank you Joel, i'm using Fedora 39, it seems it was a driver issue (?)...
i had a success by using a wire and shorting the gpio9 of the esp32-c3 to GND while resetting the chip :
https://docs.espressif.com/projects/esptool/en/latest/esp32c3/advanced-topics/boot-mode-selection.html

Closed 2024-01-23.

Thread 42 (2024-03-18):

WARNING: Failed to communicate with the flash chip, read/write operations will fail. Try checking the chip connections or removing any other hardware connected to IOs.

twertybog, 2024-03-18:
Hello!
I purchased an evil crow rf v2 on aliexpress after arriving I tried to flash it with firmware but error appeared. In arduino ide error:
```
Sketch uses 940046 bytes (71%) of program storage space. Maximum is 1310720 bytes.
Global variables use 90720 bytes (27%) of dynamic memory, leaving 236960 bytes for local variables. Maximum is 327680 bytes.
esptool.py v3.0-dev
Serial port /dev/ttyUSB0
Connecting........_____....._____....._____....._
Chip is ESP32-PICO-D4 (revision 1)
Features: WiFi, BT, Dual Core, 240MHz, Embedded Flash, VRef calibration in efuse, Coding Scheme None
Crystal is 40MHz
MAC: d4:d4:da:97:8d:f8
Uploading stub...
Running stub...
Stub running...
Changing baud rate to 921600
Changed.
Configuring flash size...
Warning: Could not auto-detect Flash size (FlashID=0x0, SizeID=0x0), defaulting to 4MB
Compressed 8192 bytes to 47...
Writing at 0x0000e000... (100 %)
Wrote 8192 bytes (47 compressed) at 0x0000e000 in 0.0 seconds (effective 19910.0 kbit/s)...
```
After that, I tried to erase flash with esptool
```
esptool.py --chip esp32 --port /dev/ttyUSB0 erase_flash
```
```
esptool.py v4.7.0
Serial port /dev/ttyUSB0
Connecting....
Chip is ESP32-PICO-D4 (revision v1.0)
Features: WiFi, BT, Dual Core, 240MHz, Embedded Flash, VRef calibration in efuse, Coding Scheme None
Crystal is 40MHz
MAC: d4:d4:da:97:8d:f8
Uploading stub...
Running stub...
Stub running...
WARNING: Failed to communicate with the flash chip, read/write operations will fail. Try checking the chip connections or removing any other hardware connected to IOs.
Erasing flash (this may take a while)...

A fatal error occurred: Packet content transfer stopped (received 3016 bytes)
```
And got info about flash
```
esptool.py --chip esp32 --port /dev/ttyUSB0 flash_id
```
```
esptool.py v4.7.0
Serial port /dev/ttyUSB0
Connecting....
Chip is ESP32-PICO-D4 (revision v1.0)
Features: WiFi, BT, Dual Core, 240MHz, Embedded Flash, VRef calibration in efuse, Coding Scheme None
Crystal is 40MHz
MAC: d4:d4:da:97:8d:f8
Uploading stub...
Running stub...
Stub running...
WARNING: Failed to communicate with the flash chip, read/write operations will fail. Try checking the chip connections or removing any other hardware connected to IOs.
Manufacturer: 00
Device: 0000
Detected flash size: Unknown
Hard resetting via RTS pin...
```

joelsernamoreno, 2024-03-18:
Hello @twertybog

What is your OS? In debian it gives some problems, in Ubuntu it should work correctly

twertybog, 2024-03-18:
> Hello @twertybog
>
> What is your OS? In debian it gives some problems, in Ubuntu it should work correctly

Thanks for response.
I use Arch. I will try Ubuntu for flashing.

lrosario, 2024-12-02:
@joelsernamoreno can u help me?

joelsernamoreno, 2024-12-02:
Hi @lrosario

I don't have macOS, I can't test this. Can you try it on Windows or Ubuntu?

lrosario, 2025-01-03:
i tried on Ubuntu, same error.

lrosario, 2025-01-16:
any updates?

samxplogs, 2025-03-27:
@lrosario I am running in similar issue, I even tried esp home and here is the issue I've got: Installation failed: Error: Packet content transfer stopped

LED1 stay in RED since the erasing process

I am wondering if this is not bricked. I do see the network ECRF, I can join and ping the gateway but nothing else.

I even got myself a second one but it seems DOA despite the fact I can flash it, no SSID found

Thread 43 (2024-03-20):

Discord

matteasd, 2024-03-20:
Hello!

Is it possible to get the discord link? :)

joelsernamoreno, 2024-03-20:
Hi @matteasd

https://discord.com/invite/7AtRFDga

crazyfox-ua, 2024-04-10:
@joelsernamoreno one more, please

crystalclear30, 2024-04-18:
May I get an invite to the Discord group please?  Just received my device and having trouble uploading sketches.  I've apparently bricked my device by changing to "Station" mode as well :(

frederikkunze, 2024-11-25:
Discord links in the description are not valid. Is the Discord not active anymore or do they need to get updated?

joelsernamoreno, 2024-11-26:
Hello @frederikkunze

Discord: https://discord.gg/CV5hD4wx

overlordtm, 2024-12-29:
Can i get discord invite please? Current one expired.

It should be possible to create a permanent invite: https://support.discord.com/hc/en-us/articles/208866998-Invites-101

wpa-2, 2024-12-29:
> Can i get discord invite please? Current one expired.
>
> It should be possible to create a permanent invite: https://support.discord.com/hc/en-us/articles/208866998-Invites-101

https://discord.gg/G6ZavyZf
yes but permanent ones do cause issues

joelsernamoreno, 2024-12-29:
Hi @overlordtm

https://discord.gg/r3Sy7jm3

cinouw, 2025-04-04:
Hi i would like to join the discord server can i get a invitation link

joelsernamoreno, 2025-04-04:
Hi @cinouw

https://discord.gg/u8R7VN4d

cinouw, 2025-04-04:
> Hi @cinouw
>
> https://discord.gg/u8R7VN4d

It's saying that it is expired 🥲

joelsernamoreno, 2025-04-04:
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

https://discord.gg/Nu6Np8YXDH

frederikkunze, 2025-04-04:
@joelsernamoreno you could also generate a link without an expiration date.
https://support.discord.com/hc/en-us/articles/208866998-Invites-101#h_01H2DMMG355MV7GJDQ9F65SDVG

joelsernamoreno, 2025-04-04:
Hi @frederikkunze

The last link is configured without expiration

Thanks

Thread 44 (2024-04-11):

Problem reading SD Card

jeff-azevedo, 2024-04-11:
Hi all! I bought a Evil Crow to start learning hardware hacking, but got stuck in the last step of the tutorial
The board's webserver simply doesn't go up. Searching for issues I find out that the SD card was not detected.

I tried the following code:

#include <SD.h>
void setup() {
Serial.begin(38400);
for (int csPin = 5; csPin <= 32; csPin++) {
if (SD.begin(csPin)) {
Serial.print("SD card detected on CS pin: ");
Serial.println(csPin);
} else {
Serial.print("No SD card found on CS pin: ");
Serial.println(csPin);
}
}
}
void loop() {}

But never got success reading the SD card.

I tried:

- Formating the SD card in FAT32 and FAT16
- Changing SD card
- Creating a file in the SD card using my PC and tried read it in the uploaded firmware

If I dont solve this issue till tomorrow I'm considering to return the board and ask for refund.

Is it a board's problem or software? Any thoughts or tips on how to solve this?

volca, 2024-04-15:
Please check [the source code v1.3.2](https://github.com/joelsernamoreno/EvilCrowRF-V2/blob/main/firmware/v1.3.2/EvilCrow-RFv2/EvilCrow-RFv2.ino#L20)

```
#define SD_SCLK 18
#define SD_MISO 19
#define SD_MOSI 23
#define SD_SS   22

SPIClass sdspi(VSPI);

// .....

void setup() {
  // ...
  sdspi.begin(18, 19, 23, 22);
  SD.begin(22, sdspi);
}
```

Did you try the default firmware? There's a compiled firmware file in the same directory.

jeff-azevedo, 2024-04-15:
Hi, thank you for answering.

I tried the default firmware (1.3.2), even the older versions (1.3.1 and 1.3.0)
The webserver actually goes up but all it returns is 404 cause it doesnt find the pages to serve (located in the SD Card)

The below code is adapted to only check if SD card is being read:
```
#include <SD.h>

#define SD_SCLK 18
#define SD_MISO 19
#define SD_MOSI 23
#define SD_SS   22

SPIClass sdspi(VSPI);

void setup() {
Serial.begin(38400);

  sdspi.begin(18, 19, 23, 22);

  if (SD.begin(22, sdspi)) {
      Serial.print("SD card detected on CS pin");
  } else {
      Serial.print("No SD card found on CS pin");
  }
}

void loop() {}
```
Always returns "No SD card found on CS pin"
Manufacturer says the board works but none of the trials worked.

volca, 2024-04-15:
Did you do the two steps?

* Copy the `EvilCrowRF-V2/firmware/v1.3.2/SD/HTML` folder to a MicroSD card.
* Copy the `EvilCrowRF-V2/firmware/v1.3.2/SD/URH` folder to a MicroSD card.

Did you find the HTML and URH folder at the root folder?

jeff-azevedo, 2024-04-15:
I did.

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

NeedMoreCoffee12, 2024-05-17:
Hi , did you manage to solve it?

jeff-azevedo, 2024-05-30:
I sent back to the manufacturer and was refunded.

NeedMoreCoffee12, 2024-05-30:
Unluckily is too late for the aliexpress manufacturer :(

Closed 2024-05-30.

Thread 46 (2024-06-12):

schematic / board layout?

mikebanz, 2024-06-12:
Hi Joel

I got a new battery for my ecrfv2 and stupidly assumed the colours on the lead were.

Now the magiscsmoke has come out of a couple of what I believe to be SOT transistors. Is there a circuit diagram and board layout available so I can fix the problem. I googled around and found a schematic for the original board (at least part of it), but I'm no wiser.

Are these resources publicly available somewhere ?

Cheers

Mmike

mikebanz, 2024-12-01:
Hi Joel,

   No worries, thanks for taking a look at it.

   Cheers

   Mike

    On 01/12/2024 05:45 NZDT Joel Serna Moreno ***@***.***> wrote:

   Hello @mikebanz
   Sorry for taking so long to reply, there are a lot of people asking for support and I don't have so much free time to reply quickly
   I will check what are the components and I will tell you this in a few days
   Thanks
   —Reply to this email directly, view it on GitHub, or unsubscribe.You are receiving this because you were mentioned.Message ID: ***@***.***>

joelsernamoreno, 2024-12-02:
Hi @mikebanz

The component is MOSFET AO3401,ESD CESD5V0AP

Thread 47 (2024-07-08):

error compiling

kavemang, 2024-07-08:
Hi getting the following error when trying to compile in IDE
```

Arduino: 1.8.19 (Windows Store 1.8.57.0) (Windows 10), Board: "ESP32 Dev Module, Disabled, Disabled, Default 4MB with spiffs (1.2MB APP/1.5MB SPIFFS), 80MHz (WiFi/BT), DIO, 40MHz, 4MB (32Mb), 921600, Core 1, Core 1, None, Disabled, Disabled"

Multiple libraries were found for "WiFiClient.h"

 Used: C:\Users\user\OneDrive\Documents\ArduinoData\packages\esp32\hardware\esp32\3.0.2\libraries\WiFi

In file included from C:\Users\user\Downloads\EvilCrowRF-V2-1.3.2\EvilCrowRF-V2-1.3.2\firmware\v1.3.2\EvilCrow-RFv2\EvilCrow-RFv2.ino:6:

 Not used: C:\Program Files\WindowsApps\ArduinoLLC.ArduinoIDE_1.8.57.0_x86__mdqgnx93n4wtt\libraries\WiFi

C:\Users\user\OneDrive\Documents\Arduino\libraries\AsyncElegantOTA\src/AsyncElegantOTA.h:4:2: error: #error AsyncElegantOTA library is deprecated, Please consider migrating to newer ElegantOTA library which now comes with an async mode. Learn More: https:

    4 | #error AsyncElegantOTA library is deprecated, Please consider migrating to newer ElegantOTA library which now comes with an async mode. Learn More: https://docs.elegantota.pro/async-mode/

      |  ^~~~~

C:\Users\user\OneDrive\Documents\Arduino\libraries\AsyncElegantOTA\src/AsyncElegantOTA.h:18:14: fatal error: esp_int_wdt.h: No such file or directory

   18 |     #include "esp_int_wdt.h"

      |              ^~~~~~~~~~~~~~~

compilation terminated.

exit status 1

Error compiling for board ESP32 Dev Module.

```

Oliver0804, 2024-08-12:
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
In the fourth line of AsyncElegantOTA.cpp:
```
#error AsyncElegantOTA library is deprecated, Please consider migrating to newer ElegantOTA library which now comes with an async mode. Learn More: https://docs.elegantota.pro/async-mode/

```
Simply remove it.

joelsernamoreno, 2024-08-12:
Hello

I've been busy these months

Looks like the library has been changed to a new version:

https://github.com/ayushsharma82/ElegantOTA

Another option is to download the new library and add it to the firmware

joelsernamoreno, 2024-10-18:
Try the new firmware version

The new firmware is compatible with the latest version of arduino ide and with the latest version of espressif esp32.

Remove all old libraries, remove the ECRF custom wifi settings and follow all the steps in the "Installation" section.

Closed 2024-11-22.

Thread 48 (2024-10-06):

Problem Connecting to Rabbit Labs Evil Crow V2

Ajekow, 2024-10-06:
Hello, I flashed all files to the ECV2 through Arduino IDE with no problem and copied the required folders to the SD card and inserted it.
When I supply it with power the SSID shows up as ESP_CAB869 and is password protected. I have tried the default password multiple times but I have not been able to connect to the ECV2.
Would anyone have a solution to this?
Thanks!

joelsernamoreno, 2024-10-18:
Try the new firmware version

Closed 2024-11-30.

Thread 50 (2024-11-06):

wdt won't allow boot after 1.3.3

lukeswitz, 2024-11-06:
Had no issues with the watchdog until this build:
```
09:15:42.871 -> E (55874) task_wdt: esp_task_wdt_reset(763): task not found
09:15:42.903 -> E (55883) task_wdt: esp_task_wdt_reset(763): task not found
09:15:42.903 -> E (55921) task_wdt: esp_task_wdt_reset(763): task not found
09:15:42.935 -> E (55922) task_wdt: esp_task_wdt_reset(763): task not found
```

lukeswitz, 2024-11-06:
seems to shut up after a bit... odd.

joelsernamoreno, 2024-11-06:
Yes, after connecting and disconnecting the device a couple of times... it doesn't seem to give error

Anyway, if it happens again try this:

Edit AsyncTCP/src/AsyncTCP.h:

#define CONFIG_ASYNC_TCP_USE_WDT 1

I have tried this and the firmware doesn't break, but I don't know if it solves wtd. In previous versions WDT 1 broke the firmware

Closed 2024-11-06.

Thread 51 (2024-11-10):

Compilation Error

korn-M, 2024-11-10:
Keep receiving the following error when trying to compile 1.3.3 EvilCrowRF-V2 using Ardiuno 2.3.3. Also using the additional board : https://espressif.github.io/arduino-esp32/package_esp32_index.json

D:\EvilCrowRF-V2-1.3.3\firmware\v1.3.3\EvilCrow-RFv2\EvilCrow-RFv2.ino:10:10: fatal error: SPIFFSEditor.h: No such file or directory
   10 | #include <SPIFFSEditor.h>
      |          ^~~~~~~~~~~~~~~~
compilation terminated.
exit status 1
Compilation error: SPIFFSEditor.h: No such file or directory

I've followed all your steps, but I don't find the SPIFFSEditor.h in the path. Not sure why it is looking for it in EvilCrow-RFv2.ino, it is not like the file can be uploaded there. Right?  Just a newbe obviously.  Thanks in advance for any assistance.

Leftfi3ld, 2024-11-10:
Im running into the same error trying to upload the sketchbook. Im using the 1.3.3 firmware with espressiff 3.0.5 and then all the libraries in the readme with the .h files updated in their .zips. here is the full error upon upload to the board.

/home/sdv/Desktop/EVILCROWWW/EvilCrowRF-V2-1.3.3/firmware/v1.3.3/EvilCrow-RFv2/EvilCrow-RFv2.ino:14:10: fatal error: SPIFFSEditor.h: No such file or directory
   14 | #include <SPIFFSEditor.h>
      |          ^~~~~~~~~~~~~~~~
compilation terminated.
exit status 1

Compilation error: SPIFFSEditor.h: No such file or directory

Korthon, 2024-11-11:
Thank you for the feedback. I checked it’s not in two places. I’m still having the issue.

Korthon, 2024-11-11:
Has the developer abandoned this program? I'm sure you're not the only one that's read this. It's very strange that all files are downloaded. SP web server has spiff editor, but Arduino can't find file or directory. Very strange.

Leftfi3ld, 2024-11-12:
No the developer is still here he just updated the firmware like 2 weeks ago to fix it for us all.

Post your error. I found my lack in arduino/c+ experience was responsible for my problems. Compiling and uploading.

Korthon, 2024-11-13:
I have no C+ experience so this is the error that I get and I don’t understand why it can’t find the spiffs editor because it’s in the library. I feel that I’ve done everything in the list correctly. But obviously not. I guess maybe I need a more step-by-step detail for my lack of experience. Thanks again for your feedback. Totally appreciated.

home/sdv/Desktop/EVILCROWWW/EvilCrowRF-V2-1.3.3/firmware/v1.3.3/EvilCrow-RFv2/EvilCrow-RFv2.ino:14:10: fatal error: SPIFFSEditor.h: No such file or directory
14 | #include <SPIFFSEditor.h>
| ^~~~~~~~~~~~~~~~
compilation terminated.
exit status 1

Compilation error: SPIFFSEditor.h: No such file or directory

compilation terminated.
exit status 1

joelsernamoreno, 2024-11-21:
Hello

Your error indicates that the SPIFFSEditor.h file does not exist

SPIFFSEditor.h is a component of the ESPAsyncWebServer library. You have to download the ESPAsyncWebServer library in your Arduino library directory as indicated in the documentation of the repository

Korthon, 2024-11-23:
Thanks for the info, ESPAasyncwebserver 3.3.22 is installed.

SoLongSidekick, 2024-11-24:
As to why you and I were missing the library file I don't know, but if you google the filename and download the SPIFFSEditor.h file you can manually move it into your EvilCrowv2 folder inside your Arduino folder.

I mean, I'm also hitting a compilation error (in case you run into it and I've solved it by then, it's "Compilation error: 'virtual bool SPIFFSEditor::canHandle(AsyncWebServerRequest*)' marked 'override', but does not override") but I got past the one you're running into by doing the above.

Korthon, 2024-11-24:
OK, I'll give that a try. Thanks for the info. Appreciate that.

Korthon, 2024-11-25:
I’ve completed numerous projects without encountering any issues. However, this particular project presents a significant challenge for me.

joelsernamoreno, 2024-11-25:
Hello @Korthon

Can you attach an image of your arduino library directory and an image of the ESPAsyncWebServer library contents?

Korthon, 2024-11-25:
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

Korthon, 2024-11-25:
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

Korthon, 2024-11-25:
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

Korthon, 2024-11-25:
Sorry I couldn't get a snapshot with my laptop

Leftfi3ld, 2024-11-29:
I would recommend adding as many of the libraries possible with the library manager. 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

Korthon, 2024-12-01:
I downloaded as many as I could. no luck. Thank you for the suggestion.

Leftfi3ld, 2024-12-02:
I was in the same boat as you and I was fried over it. You need to delete
all the libraries, delete your sketchbook. Delete the zip files and then
start from scratch...also look up the H-Rat firmware. It's pretty.

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

tcccorp, 2025-01-26:
hello,

i had exactly the same issue.

after several tries, I removed  everything about esp32, installed board esp32 by espressif  V3.0.5 and installed every lib with git clone ( even on windows) .

after files modifications ( AsyncTCP.h and ElegantOTA.h) and use right parameters, installation was done with success :)

Korthon, 2025-01-26:
Thanks, i'll give it a go.

Korthon, 2025-04-28:
Finally had time to work on evil crow. Started from scratch formatted SD card went to GitHub. downloaded https://github.com/h-RAT/EvilCrowRF_Custom_Firmware_CC1101_FlipperZero
onto Card. Then I downloaded esphomeflasher. https://github.com/h-RAT/EvilCrowRF_Custom_Firmware_CC1101_FlipperZero

When you go to download onto the SD card, extract files then just download three files from the SD card file. When you flash the evil crow with Home flasher download the complete extract file.

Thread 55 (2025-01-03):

no gateway reachable

tcccorp, 2025-01-03:
hello,

i upgraded my Evilcrow V2 with the firmware 1.3.3 and there is an issue

I'm able to see the ssid of the Evilcrow, I'm able to connect,  there is an IPv4 ( 192.168.4.2)  with a gateway 192.168.4.1.

I'm not able to ping 192.168.4.1 from my host and there is no arp address, so I'm not able to use my browser.

do you know I can debug this trouble ?

Thanks

senizokaye, 2025-01-22:
I've had the same issue.
Solved for me, when I downgraded the board version to 3.0.5
Here is my board and library versions, which works for me normally:
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

tcccorp, 2025-01-26:
hello,

thanks a lot for your answer and to be honest, shame on me because use 3.0.5 version for esp32 is on the readme :(

tcccorp

Closed 2025-01-26.

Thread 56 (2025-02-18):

please how fixe this issue SPIFFSEditor.h

salahgeek, 2025-02-18:
C:\Users\Deamon\Desktop\EvilCrowRFV2\zip\EvilCrowRF-V2-main\EvilCrowRF-V2-main\firmware\v1.3.3\EvilCrow-RFv2\EvilCrow-RFv2.ino:10:10: fatal error: SPIFFSEditor.h: No such file or directory
   10 | #include <SPIFFSEditor.h>
      |          ^~~~~~~~~~~~~~~~
compilation terminated.
exit status 1

Compilation error: SPIFFSEditor.h: No such file or directory

bmorcelli, 2025-02-21:
You need to change the version of EspAsyncWebServer to [1.3.1](https://github.com/esphome/ESPAsyncWebServer/releases/tag/v1.3.1) for it to work.

you can find this file [here](https://github.com/esphome/ESPAsyncWebServer/blob/v1.3.1/src/SPIFFSEditor.h) in this version

It may cause some other errors if you are using ESP32 v3.x framework in Arduino IDE 2.x, so you´ll need to downgrade to 2.17 or lower.

joelsernamoreno, 2025-02-21:
Hello

I am programming the firmware from scratch

In the meantime, you can use alternative firmware:

https://github.com/h-RAT/EvilCrowRF_Custom_Firmware_CC1101_FlipperZero

https://github.com/tutejshy-bit/tut-rf

If you want to use the original firmware and not waste time trying to fix the library changes, you can directly flash the .bin of version 1.3.2:

https://github.com/joelsernamoreno/EvilCrowRF-V2/blob/main/firmware/v1.3.2/EvilCrow-RFv2/EvilCrow-RFv2.ino.esp32.bin

The only difference between v1.3.2 and v1.3.3 is that v1.3.2 started to give problems with the updated libraries, I fixed this and now it is happening again

hugh-bowie, 2025-02-28:
*Awesome*.  I Had the same issue as above for about a week now. Applying corrective rollbacks now. Will advise when it works.

**Also, id be happy to correct the minor spelling errors & update the links to the various libraries that are archived for the sake of clarity in new users. Do you take PR's from strangers?**

insideout803, 2025-03-01:
Any update on this issue? I can't get any code to flash, it always runs into some kind of error. Wethers is the SPIFFSEditor.h file missing in 1.3.3 or the AsyncElegantOTA.h file missing in 1.3.2. Not sure what to do at this point?

insideout803, 2025-03-01:
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

This doen't work.

hugh-bowie, 2025-03-01:
@insideout803 This worked for me today, (Im on macOS Monterey 12.7.6, Intel Proc).

- download this bin file:   [BETA_v3.3.1_EvilCrowRF_Firmware.bin](https://github.com/h-RAT/EvilCrowRF_Custom_Firmware_CC1101_FlipperZero/blob/main/Firmware/Main/EvilCrowRF/BETA_v3.3.1_EvilCrowRF_Firmware.bin)

- download this flasher: [ESPHome-Flasher](https://github.com/esphome/esphome-flasher/releases)  ( i used the mac one  [ESPHome-Flasher-1.4.0-macOS.tar](https://github.com/esphome/esphome-flasher/releases/download/1.4.0/ESPHome-Flasher-1.4.0-macOS.tar) )

- before flashing, i put these three folders (found in that Repo with the bin file), on the empty micro sd:  [Config+HTML+SubGhz](https://github.com/h-RAT/EvilCrowRF_Custom_Firmware_CC1101_FlipperZero/tree/main/SD)

 - put that micro in the ECRF board, and plug it in to the usb, (i didnt have to push the button to go into flash mode on mac, but on windows i did)

- Open that home flasher program .. (a caution message from OS comes up talking about its outdated. click right through that crap)

- then flash it with the home flasher program mentioned above in bullet two. (mine worked with no messages, so i cant help past that point)

insideout803, 2025-03-02:
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

I appreciate it. I get "Unexpected error: ESP Chip Auto-Detection failed: Failed to connect to Espressif device: No serial data received." when attempting this. I guess something is wrong with my device. I may have bricked it trying all the other ways to configure it. FML

229311JK, 2025-03-20:
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

Thought I'd say hello, got everything to work w/latest versions of both Arduino IDE/ESP 32 core...
Kept it simple, w/the following steps.  1st, downloaded/extracted tagged folder.  2, followed link 2-SPIFFSEditor.h downloaded it.  3, opened INO, added SPIFFSEditor.h file.  4, removed the virtual C++ "override" comments.  5th & finally, removed line 10 <> comments & did this "SPIFFSEditor.h"...  Now, on programming in relation to this specific sketch.  The code itself is pretty clean/upfront from there if you look @it/understand programming.     When it comes 2-IDE I'd recommend enabling files in sketch option.  Likewise, going over SPIFFSEditor.CPP helps.   One thing I noticed, some of the structure originates to the ESP IDF master.  There 1 gets more insight into the C++ comments that caused the hang-up.  Here's where corporate pen-test security teams get there claims about manipulating the ESP's PHY layers in the most "pants fancy" way.  What they don't include is implementing this within the SOC environment 1 or 2 core will literally SMOKES the chip hardware!  Sorry 4-rambling but finally this too...

Upload settings, personally I used the ESP32-PICO variant , Core debug "Error" & upload speed 921600.  It works, uploads fast.

229311JK, 2025-03-20:
From what I'm seeing of this sketch is ALOT more can be done w/it & its user friendly.  The PICO-D4 is a solid chip in the ESP32 product line.  On the other hand.  using the h-rat software puzzles me but keep this information to myself.  On h-rat, its just a bin file folks w/no published code...  Now, I'll leave all w/this riddle/question.  Why do/did all map makers leave behind tiny errors in their works??????  ; )

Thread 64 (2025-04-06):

The Sketch is not working

0mk4rm4li, 2025-04-06:
After trying several ways to fix Arduino script nothing works any solution for that ? After flashing using .bin file try to visit 192.168.4.2 but nothing happened but ElegantOTA is working fine but not other

joelsernamoreno, 2025-04-06:
Hello @0mk4rm4li

If you can access the Wi-Fi AP and you can access Elegant OTA from the web panel it means the firmware is working

All other functionality is stored on the microSD card (HTML). Have you correctly copied the folders to the microSD and inserted the microSD into the device?

If this still does not work, try using another microSD. Some microSD cards do not work. Do not use microSD cards larger than 32gb

I use this:

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

0mk4rm4li, 2025-04-06:
It's worked, thanks

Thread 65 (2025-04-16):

Problems when flashing from source

darkwolf1000, 2025-04-16:
When I'm following the instructions it every time ends with

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

I found #56 and tried changing the ESPAsyncWebServer to the 1.3.1 but got following error

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

I don't know what to do when i uncomment "#include <SPIFFSEditor.h>" it compiles but the webserver won't show anything

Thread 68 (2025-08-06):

A little clarification on SDR Firmware

SoLongSidekick, 2025-08-06:
Heya,

So stoked to see this variant of the firmware, I just have a couple questions about using it. First, when running the commands via the serial monitor what (if anything) is expected to be read out in the monitor? The first time I gave it a try I got crickets and the second time I got a bunch of seemingly nonsensical symbols. Should I expect to see what's listed in the expected output for a successful startup? Do I need to run those 4 commands every time I want to use the Crow with URH?

Regarding running the URH bridge: I tried opening a PowerShell window where the python file is stored on my PC and running the start command but I get the error `PS F:\Code\Evil Crow\SDR Firmware> python3 urh_compatible_bridge.py
Python was not found; run without arguments to install from the Microsoft Store, or disable this shortcut from Settings > Apps > Advanced app settings > App execution aliases.` so I assume I'm missing something that's going to make me feel stupid for not figuring it out. When I tried connecting to the Crow with URH I got an error telling me the connection was actively denied by the device, but I'm sure that's because the bridge isn't running.

Could you just provide some general clarifications on exactly how to do the following?
Ensure bridge is running on port 1234 (how?)
Check serial port (/dev/cu.usbserial-140) (how? in the serial monitor? with what command?)
Verify CC1101 initialization in serial output (what's the command for this?)

I am seeing the access point so at least I know that's working correctly haha. I also see a note about removing the SD card as a troubleshooting step: should the SD slot always be vacant when using this firmware, or only if issues pop up?

Thanks in advance, I know it's a lot.

joelsernamoreno, 2025-08-08:
Hello @

I believe the SDR firmware is not functioning properly. This firmware was submitted by someone, and I accepted the PR assuming it was working correctly. However, when I tested it, I encountered the same issue — when running URH, you only see noise and strange symbols.

I have tried contacting the person who submitted the firmware, but they have not provided a solution.

If you want, you can try reaching out to them yourself in the following thread:

https://github.com/joelsernamoreno/EvilCrowRF-V2/pull/67

Sorry about this, I haven't had time to check what the problem is with this firmware

Thanks

joelsernamoreno, 2025-08-13:
Hello @SoLongSidekick

It depends on what you want to do. If you want everything centralized in a single firmware, you can use the H-RAT firmware

If you don’t need that many features, you can find most of the components separately on my GitHub. You could also use the official firmware (though it’s less powerful) or build a custom one

Most of the time, I program a basic firmware without a web panel, tailored to whatever I need at the moment

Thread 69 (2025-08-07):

Kaiju without wifi?

wrxxnch, 2025-08-07:
How to use the Kaiju if while using the device we not able to use wifi to connect to kaiju API? i'm using the H-RAT version but he doesn't answer the users

wrxxnch, 2025-08-08:
i trust you, so i'll close the "issue"

Closed 2025-08-08.

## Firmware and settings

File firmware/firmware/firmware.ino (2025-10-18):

#include "ELECHOUSE_CC1101_SRC_DRV.h"
#include <SPI.h>
#include <ESPmDNS.h>
#include <WiFiClient.h> 
#include <WiFi.h>
#include <AsyncTCP.h>
#include <ESPAsyncWebServer.h>
#include <WiFiAP.h>
#include <LittleFS.h>
#include "SD.h"

// Config SSID, password and hostname
String defaultSSID = "Evil Crow RF v2";  // Enter your SSID here
String defaultPassword = "123456789ECRFv2";  // Enter your Password here
String hostname = "evilcrow-rf"; // Enter your hostname here

// MicroSD slot pins
#define SD_SCLK 18
#define SD_MISO 19
#define SD_MOSI 23
#define SD_SS   22
SPIClass sdspi(VSPI);

// SPI Pins
int sck_pin = 14;
int miso_pin = 12;
int mosi_pin = 13;

// CC1101 Module 1
int rx_pin1 = 4;
int tx_pin1 = 2;
int cs_pin1 = 5;

// CC1101 Module 2
int rx_pin2 = 26;
int tx_pin2 = 25;
int cs_pin2 = 27;

// RF variables
#define RECEIVE_ATTR IRAM_ATTR
#define samplesize 2000
int error_toleranz = 200;
const int minsample = 30;
unsigned long sample[samplesize];
unsigned long samplesmooth[samplesize];
String lastSampleSmooth;
int  lastIndex;
int samplecount;
static unsigned long lastTime = 0;
int mod;
float deviation;
int datarate;
float frequency;
float setrxbw;
int power_jammer;
byte jammer[] = { 0xff, 0xff };
const size_t jammer_len = sizeof(jammer) / sizeof(jammer[0]);
long data_to_send[2000];

// Other variables
const bool formatOnFail = true;
String OutputLog;

// File
File logs;

// Web Server
String tmp_module;
String tmp_frequency;
String tmp_setrxbw;
String tmp_mod;
String tmp_deviation;
String tmp_datarate;
String raw_rx = "0";
String jammer_tx = "0";
String transmit;
AsyncWebServer controlserver(80);

void connectToWiFi() {
  String wifiSSID = defaultSSID;
  String wifiPassword = defaultPassword;

  if (readWiFiConfig(wifiSSID, wifiPassword)) {
    //Serial.println("Using saved Wi-Fi credentials.");
  } else {
    //Serial.println("Using default Wi-Fi credentials.");
  }

  WiFi.mode(WIFI_STA);
  WiFi.begin(wifiSSID.c_str(), wifiPassword.c_str());

  //Serial.print("Connecting to Wi-Fi: "); Serial.println(wifiSSID);
  unsigned long start = millis();

  while (WiFi.status() != WL_CONNECTED) {
    delay(500);
    //Serial.print(".");
    if (millis() - start > 15000) { 
      //Serial.println("\nFailed to connect to Wi-Fi.");
      break;
    }
  }

  if (WiFi.status() == WL_CONNECTED) {
    //Serial.print("\nConnected! IP: "); Serial.println(WiFi.localIP());
  }
}

bool readWiFiConfig(String &ssid, String &password) {
  if (!SD.exists("/wifi_config.txt")) {
    //Serial.println("Wi-Fi config file not found");
    return false;
  }

  File file = SD.open("/wifi_config.txt", FILE_READ);
  if (!file) {
    //Serial.println("Failed to open Wi-Fi config file");
    return false;
  }

  ssid = file.readStringUntil('\n');
  ssid.trim();

  password = file.readStringUntil('\n');
  password.trim();

  file.close();

  if (ssid.length() == 0 || password.length() == 0) {
    //Serial.println("Invalid Wi-Fi config (empty fields)");
    return false;
  }

  //Serial.println("Wi-Fi config read successfully:");
  //Serial.print("SSID: "); Serial.println(ssid);
  //Serial.print("Password: "); Serial.println(password);
  return true;
}

void handleUpdateWiFi(AsyncWebServerRequest *request) {
  if (request->hasParam("ssid", true) && request->hasParam("password", true)) {
    String newSSID = request->getParam("ssid", true)->value();
    String newPassword = request->getParam("password", true)->value();

    if (SD.exists("/wifi_config.txt")) {
      SD.remove("/wifi_config.txt");
      //Serial.println("Existing Wi-Fi config file deleted.");
    }

    appendFile(SD, "/wifi_config.txt", newSSID.c_str(), "\n");
    appendFile(SD, "/wifi_config.txt", newPassword.c_str(), "\n");
    request->send(200, "application/json", "{\"status\":\"success\",\"message\":\"Wi-Fi config applied successfully! Device will restart.\"}");
    delay(500);
    ESP.restart();
  } else {
    request->send(400, "application/json", "{\"status\":\"error\",\"message\":\"Missing SSID or password\"}");
  }
}

void handleDeleteWiFiConfig(AsyncWebServerRequest *request) {
  if (SD.exists("/wifi_config.txt")) {
    if (SD.remove("/wifi_config.txt")) {
      request->send(200, "application/json", "{\"status\":\"success\",\"message\":\"Wi-Fi config deleted successfully\"}");
      ESP.restart();
    } else {
      request->send(500, "application/json", "{\"status\":\"error\",\"message\":\"Failed to delete the file\"}");
    }
  } else {
    request->send(404, "application/json", "{\"status\":\"error\",\"message\":\"Wi-Fi config file not found\"}");
  }
}

void handleStats(AsyncWebServerRequest *request) {
  uint64_t cardSize = 0;
  uint64_t usedBytes = 0;
  uint64_t freeBytes = 0;
  bool sd_present = SD.cardType() != CARD_NONE;

  if (sd_present) {
    cardSize = SD.cardSize();
    freeBytes = (cardSize > usedBytes) ? (cardSize - usedBytes) : 0;
  }

  size_t freeSpiffs = 0;
  if (LittleFS.begin(true)) {
    freeSpiffs = LittleFS.totalBytes() - LittleFS.usedBytes();
  }

  float cardSizeGB = cardSize / (1024.0 * 1024.0 * 1024.0);
  //float usedGB = usedBytes / (1024.0 * 1024.0 * 1024.0);
  float freeGB = freeBytes / (1024.0 * 1024.0 * 1024.0);

  String json = "{";
  json += "\"uptime\":" + String(millis() / 1000);
  json += ",\"cpu0\":" + String(getCpuFrequencyMhz());
  json += ",\"cpu1\":" + String(getXtalFrequencyMhz());
  json += ",\"temperature\":" + String(temperatureRead());
  json += ",\"freespiffs\":" + String(freeSpiffs);
  json += ",\"sdcard_size_gb\":" + String(cardSizeGB, 2);
  json += ",\"sdcard_free_gb\":" + String(freeGB, 2);
  json += ",\"sdcard_present\":" + String(sd_present ? "true" : "false");
  json += ",\"totalram\":" + String(ESP.getHeapSize());
  json += ",\"freeram\":" + String(ESP.getFreeHeap());
  json += ",\"ssid\":\"" + WiFi.SSID() + "\"";
  json += ",\"ipaddress\":\"" + WiFi.localIP().toString() + "\"";
  json += "}";

  request->send(200, "application/json", json);
}

void appendFile(fs::FS &fs, const char * path, const char * message, String messagestring){
  logs = fs.open(path, FILE_APPEND);
  if(!logs){
    //Serial.println("Failed to open file for appending");
    return;
  }
  if(logs.print(message)|logs.print(messagestring)){
    //Serial.println("Message appended");
  } else {
    //Serial.println("Append failed");
  }
  logs.close();
}

void deleteFile(fs::FS &fs, const char * path){
  //Serial.printf("Deleting file: %s\n", path);
  if(fs.remove(path)){
    //Serial.println("File deleted");
  } else {
    //Serial.println("Delete failed");
  }
}

bool checkReceived(void) {
  delay(1);
  if (samplecount >= minsample && micros() - lastTime > 100000) {
    detachInterrupt(rx_pin1);
    detachInterrupt(rx_pin2);
    return true;
  } else {
    return false;
  }
}

void printReceived() {
  OutputLog = "";
  appendFile(SD, "/logs.txt", "-------------------------------------------------------\n", "");
  //Serial.print("Count=");
  //Serial.println(samplecount);
  OutputLog += "\n";
  OutputLog += "Count=";
  OutputLog += String(samplecount);
  OutputLog += "\n";

  for (int i = 0; i < samplecount; i++) {
    //Serial.print(sample[i]);
    //Serial.print(",");
    OutputLog += String(sample[i]);
    OutputLog += ",";
  }
  //Serial.println();
  //Serial.println();
  OutputLog += "\n";
  appendFile(SD, "/logs.txt", NULL, OutputLog.c_str());
}

void RECEIVE_ATTR receiver() {
  const long time = micros();
  const unsigned int duration = time - lastTime;

  if (duration > 100000) {
    samplecount = 0;
  }

  if (duration >= 100 && samplecount < samplesize) {
    sample[samplecount++] = duration;
  }

  /*if (duration >= 100) {
    sample[samplecount++] = duration;
  }*/

  if (samplecount >= samplesize) {
    samplecount = samplesize - 1;
    bool received = checkReceived();
    if (received) {}
    detachInterrupt(rx_pin1);
    detachInterrupt(rx_pin2);
  }

  if (mod == 0) {
    if (samplecount == 1 and digitalRead(rx_pin2) != HIGH){
      samplecount = 0;
    }

    else if (samplecount == 1 and digitalRead(rx_pin1) != HIGH){
      samplecount = 0;
    }
  }

  lastTime = time;
}

void signalanalyse(){
  OutputLog = "";
  #define signalstorage 10

  int signalanz=0;
  int timingdelay[signalstorage];
  //float pulse[signalstorage];
  long signaltimings[signalstorage*2];
  int signaltimingscount[signalstorage];
  long signaltimingssum[signalstorage];
  long signalsum=0;
  
  for (int i = 0; i<signalstorage; i++){
    signaltimings[i*2] = 100000;
    signaltimings[i*2+1] = 0;
    signaltimingscount[i] = 0;
    signaltimingssum[i] = 0;
  }
  for (int i = 1; i<samplecount; i++){
    signalsum+=sample[i];
  }

  for (int p = 0; p<signalstorage; p++){

  for (int i = 1; i<samplecount; i++){
    if (p==0){
      if (sample[i]<signaltimings[p*2]){
        signaltimings[p*2]=sample[i];
      }
    }else{
      if (sample[i]<signaltimings[p*2] && sample[i]>signaltimings[p*2-1]){
        signaltimings[p*2]=sample[i];
      }
    }
  }

  for (int i = 1; i<samplecount; i++){
    if (sample[i]<signaltimings[p*2]+error_toleranz && sample[i]>signaltimings[p*2+1]){
      signaltimings[p*2+1]=sample[i];
    }
  }

  for (int i = 1; i<samplecount; i++){
    if (sample[i]>=signaltimings[p*2] && sample[i]<=signaltimings[p*2+1]){
      signaltimingscount[p]++;
      signaltimingssum[p]+=sample[i];
    }
  }
  }
  int firstsample = signaltimings[0];
  signalanz=signalstorage;

  for (int i = 0; i<signalstorage; i++){
    if (signaltimingscount[i] == 0){
      signalanz=i;
      i=signalstorage;
    }
  }

  for (int s=1; s<signalanz; s++){
  for (int i=0; i<signalanz-s; i++){
    if (signaltimingscount[i] < signaltimingscount[i+1]){
      int temp1 = signaltimings[i*2];
      int temp2 = signaltimings[i*2+1];
      int temp3 = signaltimingssum[i];
      int temp4 = signaltimingscount[i];
      signaltimings[i*2] = signaltimings[(i+1)*2];
      signaltimings[i*2+1] = signaltimings[(i+1)*2+1];
      signaltimingssum[i] = signaltimingssum[i+1];
      signaltimingscount[i] = signaltimingscount[i+1];
      signaltimings[(i+1)*2] = temp1;
      signaltimings[(i+1)*2+1] = temp2;
      signaltimingssum[i+1] = temp3;
      signaltimingscount[i+1] = temp4;
    }
  }
  }

  for (int i=0; i<signalanz; i++){
    timingdelay[i] = signaltimingssum[i]/signaltimingscount[i];
  }

  if (firstsample == sample[1] and firstsample < timingdelay[0]){
    sample[1] = timingdelay[0];
  }

  bool lastbin=0;
  for (int i=1; i<samplecount; i++){
    float r = (float)sample[i]/timingdelay[0];
    int calculate = r;
    r = r-calculate;
    r*=10;
    if (r>=5){calculate+=1;}
    if (calculate>0){
      if (lastbin==0){
        lastbin=1;
      }else{
      lastbin=0;
    }
      if (lastbin==0 && calculate>8){
        //Serial.print(" [Pause: ");
        //Serial.print(sample[i]);
        //Serial.println(" samples]");
        OutputLog += " [Pause: ";
        OutputLog += String(sample[i]);
        OutputLog += " samples]\n";

      } else{
        for (int b=0; b<calculate; b++){
          //Serial.print(lastbin);
          OutputLog += String(lastbin);
        }
      }
    }
  }
  //Serial.println();
  //Serial.print("Samples/Symbol: ");
  //Serial.println(timingdelay[0]);
  //Serial.println();
  OutputLog += "\nSamples/Symbol: ";
  OutputLog += String(timingdelay[0]);
  OutputLog += "\n\n";

  int smoothcount=0;

  for (int i=1; i<samplecount; i++){
    float r = (float)sample[i]/timingdelay[0];
    int calculate = r;
    r = r-calculate;
    r*=10;
    if (r>=5){calculate+=1;}
    if (calculate>0){
      samplesmooth[smoothcount] = calculate*timingdelay[0];
      smoothcount++;
    }
  }
  appendFile(SD, "/logs.txt", NULL, "\n");
  //Serial.println("Rawdata corrected:");
  //Serial.print("Count=");
  //Serial.println(smoothcount+1);
  lastIndex = smoothcount - 1;
  lastSampleSmooth = samplesmooth[lastIndex];

  OutputLog += "Rawdata corrected:\n";
  OutputLog += "Count=";
  OutputLog += String(smoothcount + 1);
  OutputLog += "\n";

  for (int i=0; i<smoothcount; i++){
    //Serial.print(samplesmooth[i]);
    //Serial.print(",");
    OutputLog += String(samplesmooth[i]);
    OutputLog += ",";
  }
  //Serial.println();
  //Serial.println();
  appendFile(SD, "/logs.txt", NULL, OutputLog.c_str());
  appendFile(SD, "/logs.txt", NULL, "\n");
  appendFile(SD, "/logs.txt", "-------------------------------------------------------\n", "");
  return;
}

void enableReceive() {
  rx_pin1 = digitalPinToInterrupt(rx_pin1);
  rx_pin2 = digitalPinToInterrupt(rx_pin2);
  pinMode(rx_pin1, INPUT);
  pinMode(rx_pin2, INPUT);
  ELECHOUSE_cc1101.SetRx();
  samplecount = 0;
  attachInterrupt(rx_pin1, receiver, CHANGE);
  attachInterrupt(rx_pin2, receiver, CHANGE);
}

void setup() {
  Serial.begin(38400);

  if (!LittleFS.begin(true)) {
    LittleFS.format();
    delay(1000);
    ESP.restart();
  }

  delay(2000);
  sdspi.begin(18, 19, 23, 22);
  SD.begin(22, sdspi);

  connectToWiFi();

  if (!MDNS.begin(hostname.c_str())) {
    //Serial.println("Error setting up MDNS responder!");
  }

  controlserver.on("/", HTTP_GET, [](AsyncWebServerRequest *request) {
    request->send(SD, "/HTML/index.html", "text/html");
  });

  controlserver.on("/rxconfig", HTTP_GET, [](AsyncWebServerRequest *request) {
    request->send(SD, "/HTML/rxconfig.html", "text/html");
  });

  controlserver.on("/viewlog", HTTP_GET, [](AsyncWebServerRequest *request){
    request->send(SD, "/HTML/viewlog.html", "text/html");
  });

  controlserver.on("/logs", HTTP_GET, [](AsyncWebServerRequest *request){
    request->send(SD, "/logs.txt", "text/plain");
  });

  controlserver.on("/txconfig", HTTP_GET, [](AsyncWebServerRequest *request) {
    request->send(SD, "/HTML/txconfig.html", "text/html");
  });

  controlserver.on("/delete", HTTP_POST, [](AsyncWebServerRequest *request){
    deleteFile(SD, "/logs.txt");
    request->send(200, "application/json", "{\"status\":\"deleted\"}");
  });

  controlserver.on("/config", HTTP_GET, [](AsyncWebServerRequest *request){
    request->send(SD, "/HTML/config.html", "text/html");
  });

  controlserver.on("/updatewifi", HTTP_POST, handleUpdateWiFi);
  controlserver.on("/deletewificonfig", HTTP_POST, handleDeleteWiFiConfig);
  controlserver.on("/stats", HTTP_GET, handleStats);

  controlserver.on("/reboot", HTTP_POST, [](AsyncWebServerRequest *request){
    request->send(200, "application/json", "{\"success\":true,\"message\":\"Device rebooting\"}");
    delay(200);
    ESP.restart();
  });

  controlserver.on("/connectioncheck", HTTP_GET, [](AsyncWebServerRequest *request) {
    request->send(200, "application/json", "{\"status\":\"ok\"}");
  });

  controlserver.on("/javascript.js", HTTP_GET, [](AsyncWebServerRequest *request) {
    request->send(SD, "/HTML/javascript.js", "text/javascript");
  });

  controlserver.on("/setrx", HTTP_POST, [](AsyncWebServerRequest *request) {
    if (!request->hasArg("module") || !request->hasArg("frequency") ||
      !request->hasArg("setrxbw") || !request->hasArg("mod") ||
      !request->hasArg("deviation") || !request->hasArg("datarate")) {

      request->send(400, "application/json", "{\"status\":\"error\",\"message\":\"Missing parameters\"}");
      return;
    }

    tmp_module = request->arg("module");
    tmp_frequency = request->arg("frequency");
    tmp_setrxbw = request->arg("setrxbw");
    tmp_mod = request->arg("mod");
    tmp_deviation = request->arg("deviation");
    tmp_datarate = request->arg("datarate");

    if (request->hasArg("configmodule")) {
      frequency = tmp_frequency.toFloat();
      setrxbw = tmp_setrxbw.toFloat();
      mod = tmp_mod.toInt();
      deviation = tmp_deviation.toFloat();
      datarate = tmp_datarate.toInt();

      if (tmp_module == "1") {
        ELECHOUSE_cc1101.setModul(0);
        ELECHOUSE_cc1101.Init();
      } else if (tmp_module == "2") {
        ELECHOUSE_cc1101.setModul(1);
        ELECHOUSE_cc1101.Init();
      }

      if (mod == 2) {
        ELECHOUSE_cc1101.setDcFilterOff(0);
      } else if (mod == 0) {
        ELECHOUSE_cc1101.setDcFilterOff(1);
        ELECHOUSE_cc1101.setDeviation(deviation);
      }

      ELECHOUSE_cc1101.setModulation(mod);
      ELECHOUSE_cc1101.setMHZ(frequency);
      ELECHOUSE_cc1101.setSyncMode(0);
      ELECHOUSE_cc1101.setPktFormat(3);
      ELECHOUSE_cc1101.setRxBW(setrxbw);
      ELECHOUSE_cc1101.setDRate(datarate);
      enableReceive();
      raw_rx = "1";
      request->send(200, "application/json", "{\"status\":\"success\",\"message\":\"RX configuration applied successfully.\"}");
    } else {
      request->send(400, "application/json", "{\"status\":\"error\",\"message\":\"Missing configmodule parameter\"}");
    }
  });

  controlserver.on("/stoprx", HTTP_POST, [](AsyncWebServerRequest *request) {
    ELECHOUSE_cc1101.setModul(0);
    ELECHOUSE_cc1101.setSidle();
    ELECHOUSE_cc1101.setModul(1);
    ELECHOUSE_cc1101.setSidle();

    raw_rx = "0";
    request->send(200, "application/json", "{\"status\":\"success\",\"message\":\"RX stopped.\"}");
  });

  controlserver.on("/settx", HTTP_POST, [](AsyncWebServerRequest *request){
    if (!request->hasArg("module") || !request->hasArg("frequency") || 
      !request->hasArg("rawdata") || !request->hasArg("mod") || !request->hasArg("deviation")) {
      request->send(400, "text/plain", "Missing parameters");
      return;
    }

    tmp_module = request->arg("module");
    tmp_frequency = request->arg("frequency");
    transmit = request->arg("rawdata");
    tmp_deviation = request->arg("deviation");
    tmp_mod = request->arg("mod");

    int counter = 0;
    int pos = 0;
    frequency = tmp_frequency.toFloat();
    deviation = tmp_deviation.toFloat();
    mod = tmp_mod.toInt();

    for (int i = 0; i < transmit.length(); i++){
      if (transmit.substring(i, i+1) == ",") {
        data_to_send[counter++] = transmit.substring(pos, i).toInt();
        pos = i+1;
      }
    }
    if (pos < transmit.length()) data_to_send[counter++] = transmit.substring(pos).toInt();

    int tx_pin = (tmp_module == "1") ? 2 : 25;
    ELECHOUSE_cc1101.setModul((tmp_module == "1") ? 0 : 1);
    ELECHOUSE_cc1101.Init();
    ELECHOUSE_cc1101.setModulation(mod);
    ELECHOUSE_cc1101.setMHZ(frequency);
    ELECHOUSE_cc1101.setDeviation(deviation);
    ELECHOUSE_cc1101.SetTx();
    pinMode(tx_pin, OUTPUT);

    for (int i = 0; i < counter; i += 2) {
      digitalWrite(tx_pin, HIGH);
      delayMicroseconds(data_to_send[i]);
      digitalWrite(tx_pin, LOW);
      delayMicroseconds(data_to_send[i+1]);
      //Serial.print(data_to_send[i]);
      //Serial.print(",");
    }

    ELECHOUSE_cc1101.setSidle();
    request->send(200, "text/plain", "Signal has been transmitted");
});


  controlserver.on("/setjammer", HTTP_POST, [](AsyncWebServerRequest *request){
    if (!request->hasArg("module") || !request->hasArg("frequency") || !request->hasArg("power")) {
      request->send(400, "application/json", "{\"status\":\"error\",\"message\":\"Missing parameters (module, frequency, power required)\"}");
      return;
    }

    tmp_module = request->arg("module");
    frequency = request->arg("frequency").toFloat();
    int power_jammer = request->arg("power").toInt();

    if (tmp_module != "1" && tmp_module != "2") {
      request->send(400, "application/json", "{\"status\":\"error\",\"message\":\"Invalid module (must be 1 or 2)\"}");
      return;
    }

    int moduleIndex = (tmp_module == "1") ? 0 : 1;
    int tx_pin = (tmp_module == "1") ? tx_pin1 : tx_pin2;

    pinMode(tx_pin, OUTPUT);
    ELECHOUSE_cc1101.setModul(moduleIndex);
    ELECHOUSE_cc1101.Init();
    ELECHOUSE_cc1101.setModulation(2);
    ELECHOUSE_cc1101.setMHZ(frequency);
    ELECHOUSE_cc1101.setPA(power_jammer);
    ELECHOUSE_cc1101.SetTx();

    jammer_tx = "1";
    request->send(200, "application/json", "{\"status\":\"success\",\"message\":\"Jammer started\"}");
  });

  controlserver.on("/stopjammer", HTTP_POST, [](AsyncWebServerRequest *request) {
    ELECHOUSE_cc1101.setModul(0);
    ELECHOUSE_cc1101.setSidle();
    ELECHOUSE_cc1101.setModul(1);
    ELECHOUSE_cc1101.setSidle();

    jammer_tx = "0";
    request->send(200, "application/json", "{\"status\":\"success\",\"message\":\"Jammer stopped\"}");
  });

  controlserver.on("/style.css", HTTP_GET, [](AsyncWebServerRequest *request) {
    request->send(SD, "/HTML/style.css", "text/css");
  });

  controlserver.begin();
  ELECHOUSE_cc1101.addSpiPin(sck_pin, miso_pin, mosi_pin, cs_pin1, 0);
  ELECHOUSE_cc1101.addSpiPin(sck_pin, miso_pin, mosi_pin, cs_pin2, 1);
  
  enableReceive();
}

void loop() {
  if(raw_rx == "1") {
    if(checkReceived()){
      printReceived();
      signalanalyse();
      enableReceive();
      delay(700);
    }
  }
  if(jammer_tx == "1") {
    if (tmp_module == "1") {
      for (int i = 0; i + 1 < jammer_len; i += 2){
        digitalWrite(tx_pin1,HIGH);
        delayMicroseconds(jammer[i]);
        digitalWrite(tx_pin1,LOW);
        delayMicroseconds(jammer[i+1]);
      }
    }
    else if (tmp_module == "2") {
      for (int i = 0; i + 1 < jammer_len; i += 2){
        digitalWrite(tx_pin2,HIGH);
        delayMicroseconds(jammer[i]);
        digitalWrite(tx_pin2,LOW);
        delayMicroseconds(jammer[i+1]);
      }
    }
  }
}

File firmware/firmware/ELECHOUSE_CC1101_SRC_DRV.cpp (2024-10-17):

/*
  ELECHOUSE_CC1101.cpp - CC1101 module library
  Copyright (c) 2010 Michael.
    Author: Michael, <www.elechouse.com>
    Version: November 12, 2010

  This library is designed to use CC1101/CC1100 module on Arduino platform.
  CC1101/CC1100 module is an useful wireless module.Using the functions of the 
  library, you can easily send and receive data by the CC1101/CC1100 module. 
  Just have fun!
  For the details, please refer to the datasheet of CC1100/CC1101.
----------------------------------------------------------------------------------------------------------------
cc1101 Driver for RC Switch. Mod by Little Satan. With permission to modify and publish Wilson Shen (ELECHOUSE).
----------------------------------------------------------------------------------------------------------------
*/
#include <SPI.h>
#include "ELECHOUSE_CC1101_SRC_DRV.h"
#include <Arduino.h>

/****************************************************************/
#define   WRITE_BURST       0x40            //write burst
#define   READ_SINGLE       0x80            //read single
#define   READ_BURST        0xC0            //read burst
#define   BYTES_IN_RXFIFO   0x7F            //byte number in RXfifo
#define   max_modul 6

SPIClass CCSPI(HSPI);

byte modulation = 2;
byte frend0;
byte chan = 0;
int pa = 12;
byte last_pa;
byte SCK_PIN;
byte MISO_PIN;
byte MOSI_PIN;
byte SS_PIN;
byte GDO0;
byte GDO2;
byte SCK_PIN_M[max_modul];
byte MISO_PIN_M[max_modul];
byte MOSI_PIN_M[max_modul];
byte SS_PIN_M[max_modul];
byte GDO0_M[max_modul];
byte GDO2_M[max_modul];
byte gdo_set=0;
bool spi = 0;
bool ccmode = 0;
float MHz = 433.92;
byte m4RxBw = 0;
byte m4DaRa;
byte m2DCOFF;
byte m2MODFM;
byte m2MANCH;
byte m2SYNCM;
byte m1FEC;
byte m1PRE;
byte m1CHSP;
byte pc1PQT;
byte pc1CRC_AF;
byte pc1APP_ST;
byte pc1ADRCHK;
byte pc0WDATA;
byte pc0PktForm;
byte pc0CRC_EN;
byte pc0LenConf;
byte trxstate = 0;
byte clb1[2]= {24,28};
byte clb2[2]= {31,38};
byte clb3[2]= {65,76};
byte clb4[2]= {77,79};

/****************************************************************/
uint8_t PA_TABLE[8]     {0x00,0xC0,0x00,0x00,0x00,0x00,0x00,0x00};
//                       -30  -20  -15  -10   0    5    7    10
uint8_t PA_TABLE_315[8] {0x12,0x0D,0x1C,0x34,0x51,0x85,0xCB,0xC2,};             //300 - 348
uint8_t PA_TABLE_433[8] {0x12,0x0E,0x1D,0x34,0x60,0x84,0xC8,0xC0,};             //387 - 464
//                        -30  -20  -15  -10  -6    0    5    7    10   12
uint8_t PA_TABLE_868[10] {0x03,0x17,0x1D,0x26,0x37,0x50,0x86,0xCD,0xC5,0xC0,};  //779 - 899.99
//                        -30  -20  -15  -10  -6    0    5    7    10   11
uint8_t PA_TABLE_915[10] {0x03,0x0E,0x1E,0x27,0x38,0x8E,0x84,0xCC,0xC3,0xC0,};  //900 - 928
/****************************************************************
*FUNCTION NAME:SpiStart
*FUNCTION     :spi communication start
*INPUT        :none
*OUTPUT       :none
****************************************************************/
void ELECHOUSE_CC1101::SpiStart(void)
{
  // initialize the SPI pins
  pinMode(SCK_PIN, OUTPUT);
  pinMode(MOSI_PIN, OUTPUT);
  pinMode(MISO_PIN, INPUT);
  pinMode(SS_PIN, OUTPUT);

  // enable SPI
  #ifdef ESP32
  CCSPI.begin(SCK_PIN, MISO_PIN, MOSI_PIN, SS_PIN);
  #else
  CCSPI.begin();
  #endif
}
/****************************************************************
*FUNCTION NAME:SpiEnd
*FUNCTION     :spi communication disable
*INPUT        :none
*OUTPUT       :none
****************************************************************/
void ELECHOUSE_CC1101::SpiEnd(void)
{
  // disable SPI
  CCSPI.endTransaction();
  CCSPI.end();
}
/****************************************************************
*FUNCTION NAME: GDO_Set()
*FUNCTION     : set GDO0,GDO2 pin for serial pinmode.
*INPUT        : none
*OUTPUT       : none
****************************************************************/
void ELECHOUSE_CC1101::GDO_Set (void)
{
	pinMode(GDO0, OUTPUT);
	pinMode(GDO2, INPUT);
}
/****************************************************************
*FUNCTION NAME: GDO_Set()
*FUNCTION     : set GDO0 for internal transmission mode.
*INPUT        : none
*OUTPUT       : none
****************************************************************/
void ELECHOUSE_CC1101::GDO0_Set (void)
{
  pinMode(GDO0, INPUT);
}
/****************************************************************
*FUNCTION NAME:Reset
*FUNCTION     :CC1101 reset //details refer datasheet of CC1101/CC1100//
*INPUT        :none
*OUTPUT       :none
****************************************************************/
void ELECHOUSE_CC1101::Reset (void)
{
	digitalWrite(SS_PIN, LOW);
	delay(1);
	digitalWrite(SS_PIN, HIGH);
	delay(1);
	digitalWrite(SS_PIN, LOW);
	while(digitalRead(MISO_PIN));
  CCSPI.transfer(CC1101_SRES);
  while(digitalRead(MISO_PIN));
	digitalWrite(SS_PIN, HIGH);
}
/****************************************************************
*FUNCTION NAME:Init
*FUNCTION     :CC1101 initialization
*INPUT        :none
*OUTPUT       :none
****************************************************************/
void ELECHOUSE_CC1101::Init(void)
{
  setSpi();
  SpiStart();                   //spi initialization
  digitalWrite(SS_PIN, HIGH);
  digitalWrite(SCK_PIN, HIGH);
  digitalWrite(MOSI_PIN, LOW);
  Reset();                    //CC1101 reset
  RegConfigSettings();            //CC1101 register config
  SpiEnd();
}
/****************************************************************
*FUNCTION NAME:SpiWriteReg
*FUNCTION     :CC1101 write data to register
*INPUT        :addr: register address; value: register value
*OUTPUT       :none
****************************************************************/
void ELECHOUSE_CC1101::SpiWriteReg(byte addr, byte value)
{
  SpiStart();
  digitalWrite(SS_PIN, LOW);
  while(digitalRead(MISO_PIN));
  CCSPI.transfer(addr);
  CCSPI.transfer(value); 
  digitalWrite(SS_PIN, HIGH);
  SpiEnd();
}
/****************************************************************
*FUNCTION NAME:SpiWriteBurstReg
*FUNCTION     :CC1101 write burst data to register
*INPUT        :addr: register address; buffer:register value array; num:number to write
*OUTPUT       :none
****************************************************************/
void ELECHOUSE_CC1101::SpiWriteBurstReg(byte addr, byte *buffer, byte num)
{
  byte i, temp;
  SpiStart();
  temp = addr | WRITE_BURST;
  digitalWrite(SS_PIN, LOW);
  while(digitalRead(MISO_PIN));
  CCSPI.transfer(temp);
  for (i = 0; i < num; i++)
  {
  CCSPI.transfer(buffer[i]);
  }
  digitalWrite(SS_PIN, HIGH);
  SpiEnd();
}
/****************************************************************
*FUNCTION NAME:SpiStrobe
*FUNCTION     :CC1101 Strobe
*INPUT        :strobe: command; //refer define in CC1101.h//
*OUTPUT       :none
****************************************************************/
void ELECHOUSE_CC1101::SpiStrobe(byte strobe)
{
  SpiStart();
  digitalWrite(SS_PIN, LOW);
  while(digitalRead(MISO_PIN));
  CCSPI.transfer(strobe);
  digitalWrite(SS_PIN, HIGH);
  SpiEnd();
}
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

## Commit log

2022-05-25 Add Evil Crow RF V2 Case
    [ECRFV2_1_2_3_BUTTON.stl, ECRFV2_BOTTOM.stl, ECRFV2_CAP.stl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]
2022-05-25 correction incorrect format
    [ECRFV2_CAP.stl]
2023-03-05 Case remixed & added solidworks files
    [Bottom.SLDPRT, NCRFV1_BUTTON_LONG.STL, NCRFV1_BUTTON_SHORT.stl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]
2025-05-26 Add enhanced SDR firmware with URH integration
    - Professional SDR capabilities for EvilCrow RF v2
    - URH (Universal Radio Hacker) compatibility via RTL-TCP bridge
    - Modern web interface with real-time updates and professional design
    - Python SDK for automation and custom applications
    - GNU Radio integration examples and flowgraph compatibility
    - Proper CC1101 library integration for reliable RF operation
    - HackRF protocol compatibility for standard SDR tools
    Technical improvements:
    - Correct SPI pin configuration for EvilCrow hardware
    - Real CC1101 FIFO data processing instead of synthetic samples
    - Stable RF communication with proper library usage
    - RESTful API for remote control and automa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
    [ECRFv2-SDR.ino, ELECHOUSE_CC1101_SRC_DRV.cpp, EvilCrowSDR_Python_Library.py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]
